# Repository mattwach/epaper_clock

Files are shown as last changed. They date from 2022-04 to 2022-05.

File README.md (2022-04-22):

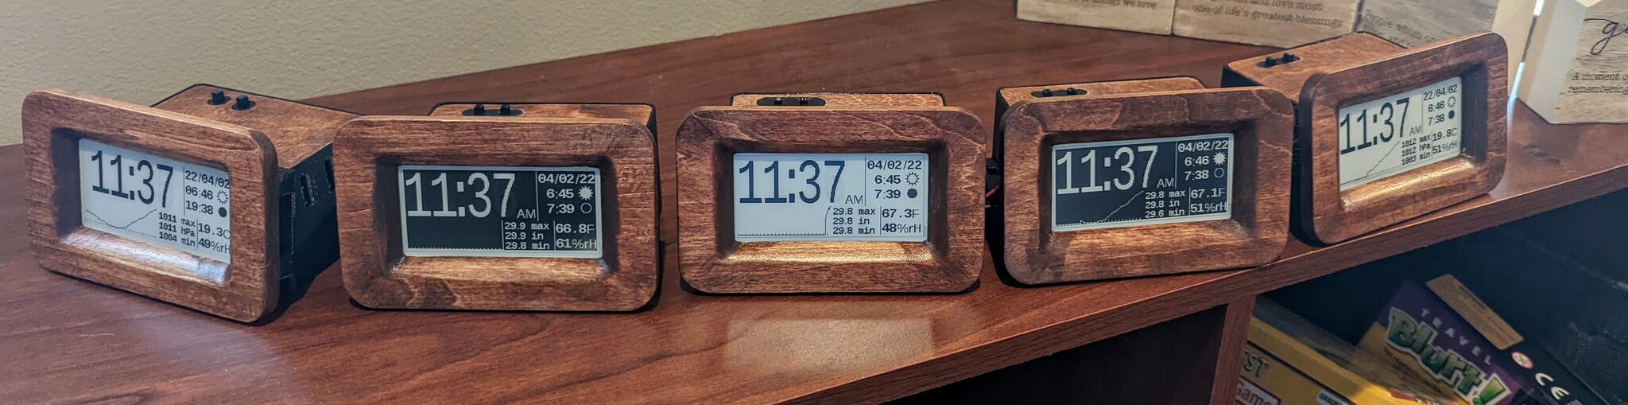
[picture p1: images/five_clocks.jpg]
Five Clocks

# EPaper Clock and Weather Station

This project is an EPaper clock and weather station that automatically sets
itself (via GPS) and can be built to last about 6 months on 4 AAA batteries.
It purposefully does not need any network connections for the sake of security
and reliability.

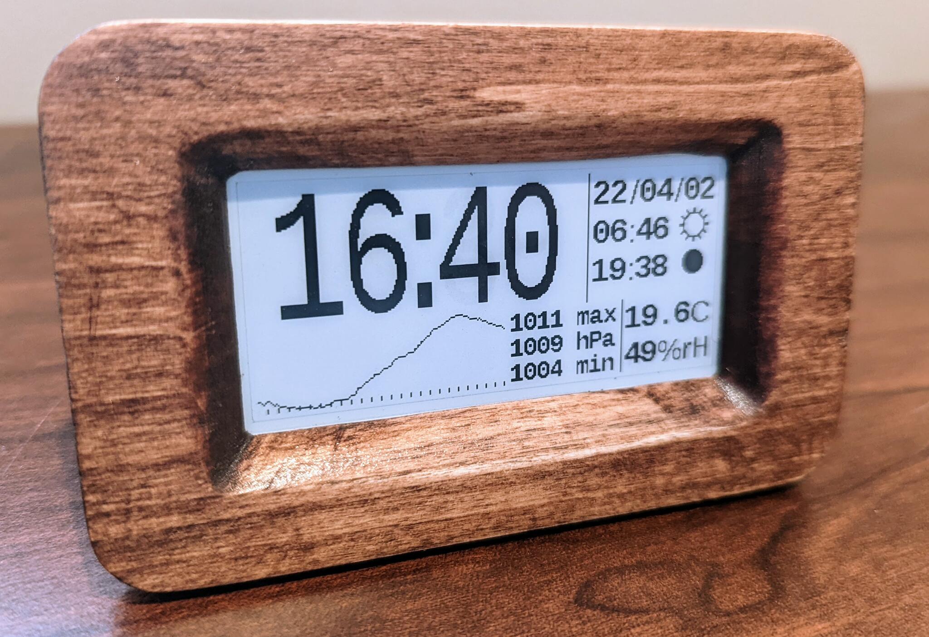
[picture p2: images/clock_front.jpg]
Clock Front


Here is a video overview:

IMAGE ALT TEXT (http://www.youtube.com/watch?v=99J65S5GTPI "EPaper Clock Video")

Features include:

   * Autoset (via GPS)
   * Current temperature.
   * Current humidity.
   * A pressure graph showing pressure over the last 25 hours.
   * Sunrise and Sunset times
   * Current moon phase
   * Select between 12h or 24h modes.
   * Select between English and metric units.

I put together two main variants of the project: "easy" and "low power".

The "easy" version is based on the Arduino Nano.  The intent with this
variation is to minimize cost and part count. The downside is that you'll need
to power the clock from a USB 5V adapter.

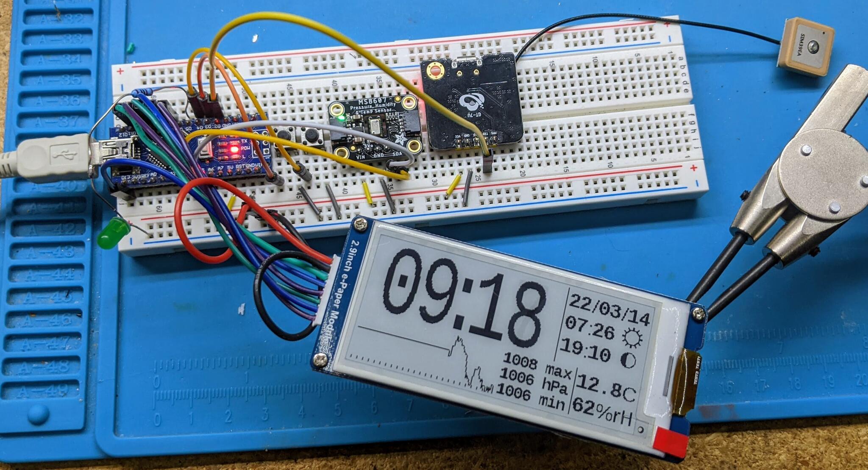
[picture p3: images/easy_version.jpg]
Easy Version


The "low power" version replaces the nano with a bare Atmega328P chip,
configured with a 32k crystal.  Under this configuration, the chip uses < 1
uA except when it is woken up by the crystal once per second.  This means
that the clock can be powered for a long time on batteries, even when power
draw from other devices is accounted for (all devices included draw 30-70
uA during while sleeping, and they are sleeping most of the time).

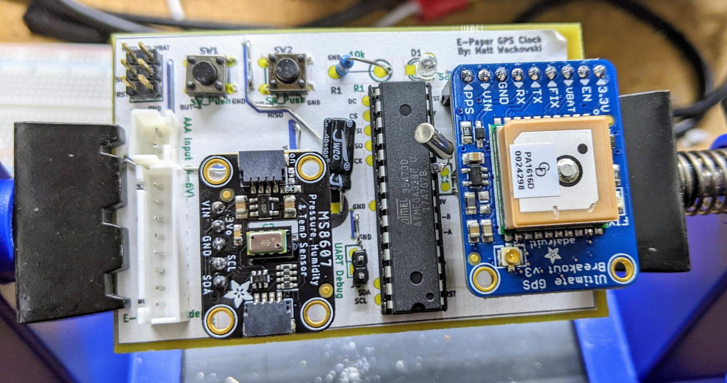
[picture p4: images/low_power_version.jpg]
Low Power Version


Both versions are designed to be buildable on a breadboard for experimentation.
The final board is designed to be buildable by any of several techniques:
prototype boards, CNC milling, chemical etchings, or ordering a PCB from the
provided design files are all options.

# Parts List

## "Easy" version

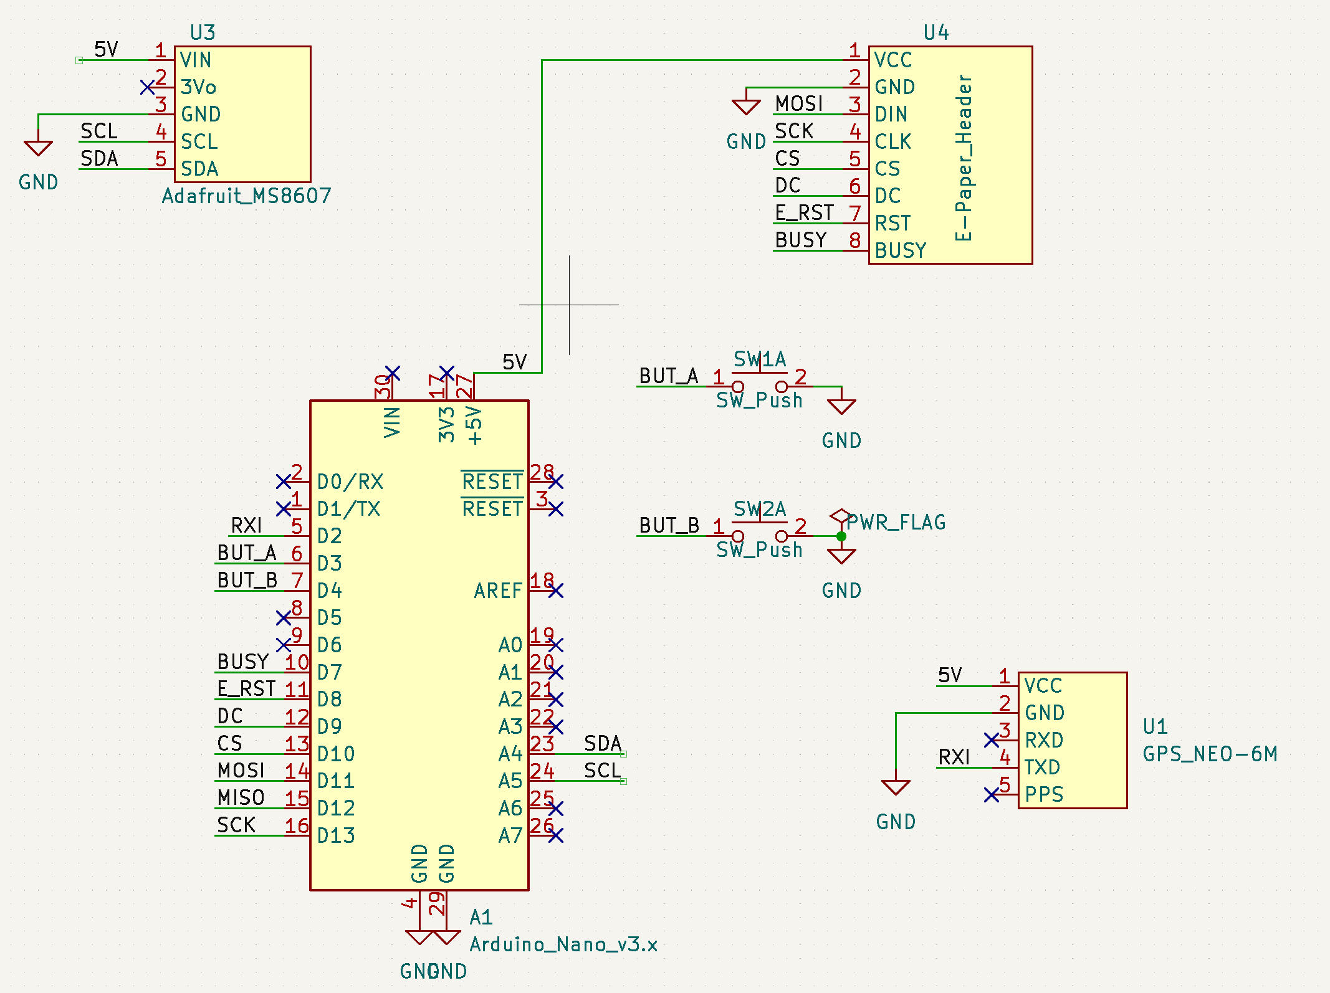
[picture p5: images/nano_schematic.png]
Nano Schematic


   * _Arduino Nano (or clone) ($3)_.  I went with a
     [clone board on Amazon](https://www.amazon.com/ELEGOO-Arduino-ATmega328P-Without-Compatible/dp/B0713XK923) but
     with April 2022 prices, I'd consider ebay as well.
   * _Waveshare 2.9 in EPaper Module ($22)_.  Purchase direct from Waveshare or
     [from amazon](https://www.amazon.com/2-9inch-Display-Module-Two-Color-Interface/dp/B07VD1V1YB).
   * _Adafruit MS8607 Pressure / Humidity / Temperature Sensor ($15)_.
     [link](https://www.adafruit.com/product/4716) I chose this one because of
     it's low power draw.
   * _Any basic GPS module with 9600 Baud TX_ ($12).  I went with
     [this one](https://smile.amazon.com/gp/product/B07P8YMVNT)
   * _Circuit Board_: This might be a
     [prototype board](https://www.amazon.com/ELEGOO-Prototype-Soldering-Compatible-Arduino/dp/B072Z7Y19F) OR
     [a piece of copper clad for CNC](https://www.amazon.com/MCIGICM-Copper-Laminate-Circuit-Single/dp/B01MCVLDDZ) OR
     you might opt to order a [prefabricated PCB](https://oshpark.com/).
   * _A couple of push switches_: [link](https://www.adafruit.com/product/1119)
     These are used to change the UTC time offset and display preferences.
   * _Materials to build a case_: I provide `.3mf`, `.scad`, and `.dxf` files
     if you would like to use a 3D printer, laser cutter, or CNC machine (I
     used a 3D printer and CNC), but you can also do a personalized case if you want.
   * _USB charger and cable_: To power the unit

## "Low Power" version

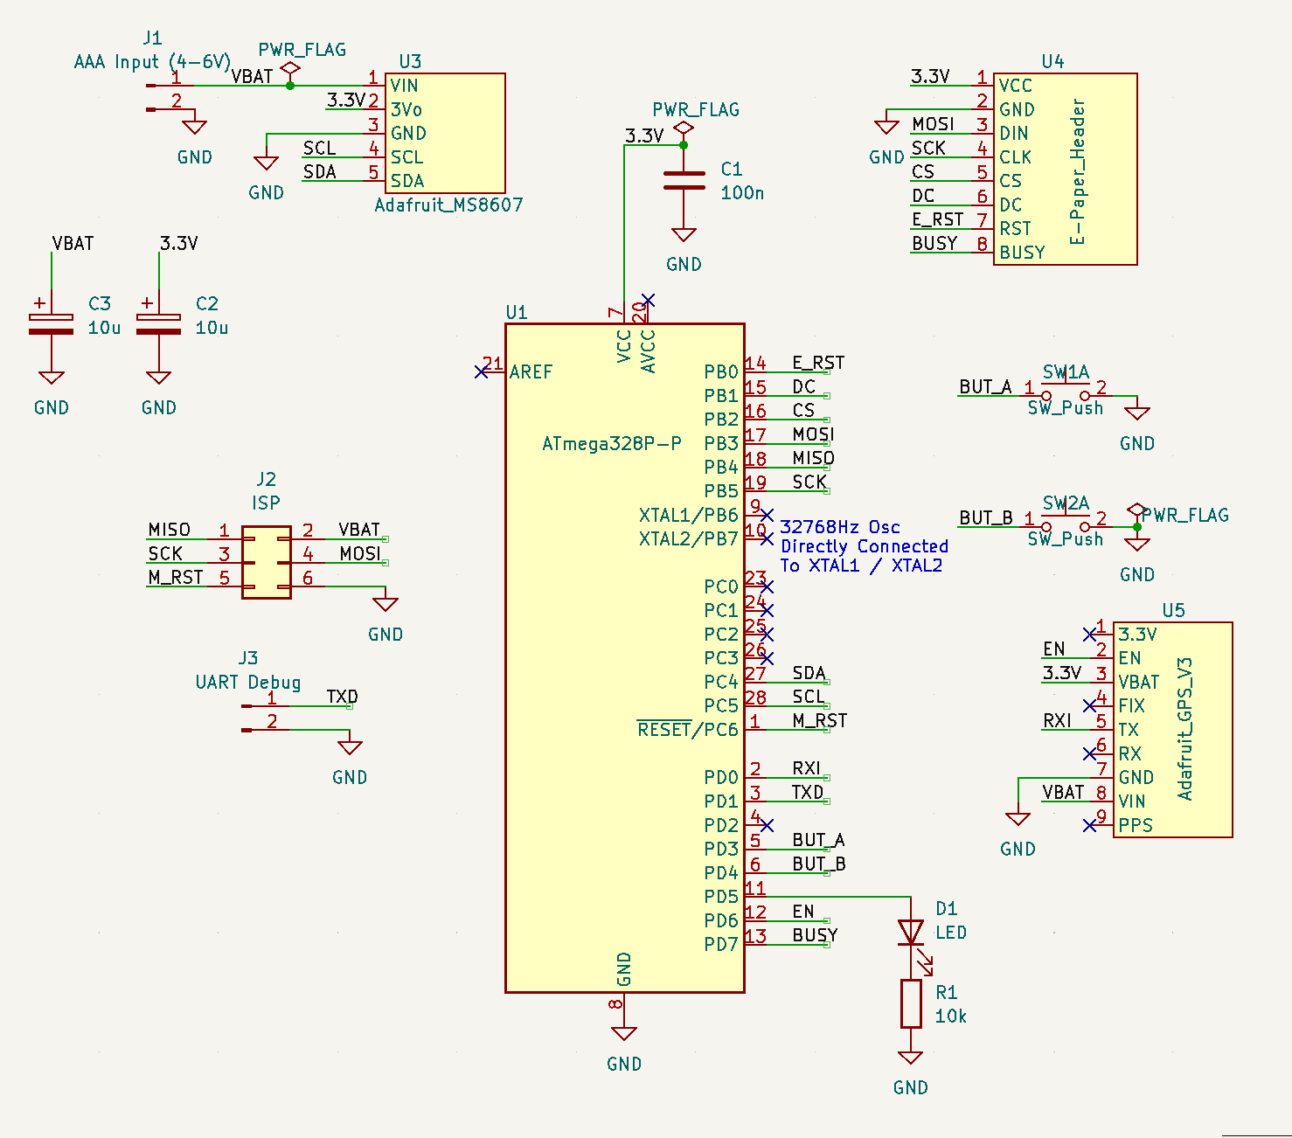
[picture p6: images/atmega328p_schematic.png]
Nano Schematic


From the "easy" version above, you will need:

   * Waveshare 2.9 in EPaper Module
   * Adafruit MS8607 PHT monitor
   * Circuit board
   * Push switches
   * Case materials

You will also need

   * _Atmega328P DIP version ($2)_.
     [link](https://www.digikey.com/en/products/detail/microchip-technology/ATMEGA328P-PU/1914589)
     You can alternately opt for an SMD package version but soldering on the
     32k crystal will be harder.
   * _32768 Hz Crystal (<$1)_. [link](https://www.amazon.com/gp/product/B07Z2V95MJ)
     This oscillator is the key to low power in the design.
   * _Adafruit GPS Module ($30)_ [link](https://www.adafruit.com/product/746)
     This module is a bit higher quality than the one in the "easy" version in
     that it can track more satellites (for faster lock), provides and enable
     pin (for low power) and a port for keeping its memory active (for fast
     relock).  If all those features don't justify the added cost for you, you
     can hack a cheaper module to do the job by adding your own enable FET.  I
     explain how in upcoming steps.
   * _LED + Resistor_  The bare Atmega328P has no way to tell you if it's
     working, locked up, etc.  The blinking light thus provides a 1ms / second
     "heartbeat" that consumes almost no power but provides useful feedback.
     If you don't feel like you need it, you can omit it.
   * A couple of 10 uF and a 100 nF capacitors to smooth the power, which
     ranges from 50 uA to around 5-6 mA when refreshing the screen.
     If you feel lucky, you can try omitting these.
   * A 3x2 pin header for programming the chip via ICSP.  If you only program
     the chip off-board, you will not need this.
   * _Optional: A 1x2 pin header for UART debugging_.  You will only need this
     if the board is acting erratically.

## Arduino Mini version

I said there were two version but this is a bonus one (V2.5?).  It exists
because we live in a "parts drought" where chips like the Atmega328P go out of
stock for long periods.

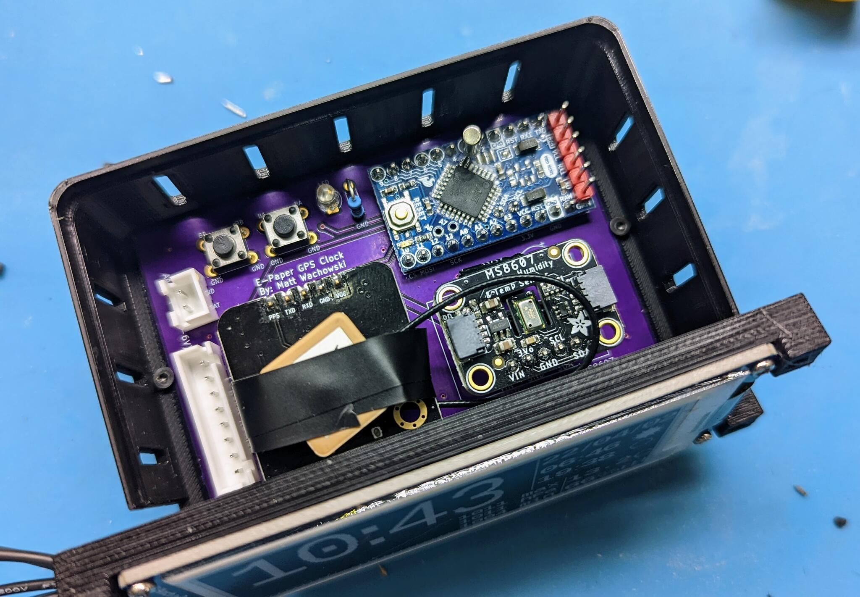
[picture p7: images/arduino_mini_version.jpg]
Arduino Mini Version


You can run this version with the "easy" firmware or, if you have
the soldering confidence, you can solder a 32k crystal on the board and go with the
32k version of the firmware (more details on the next section).

Here is the schematic.  This one is wired with a "cheap GPS" solution but you
can also go with the Adafruit GPS if you replace the GPS part of the schematic
with the Adafruit setup (as illustrated in the low power schematic).

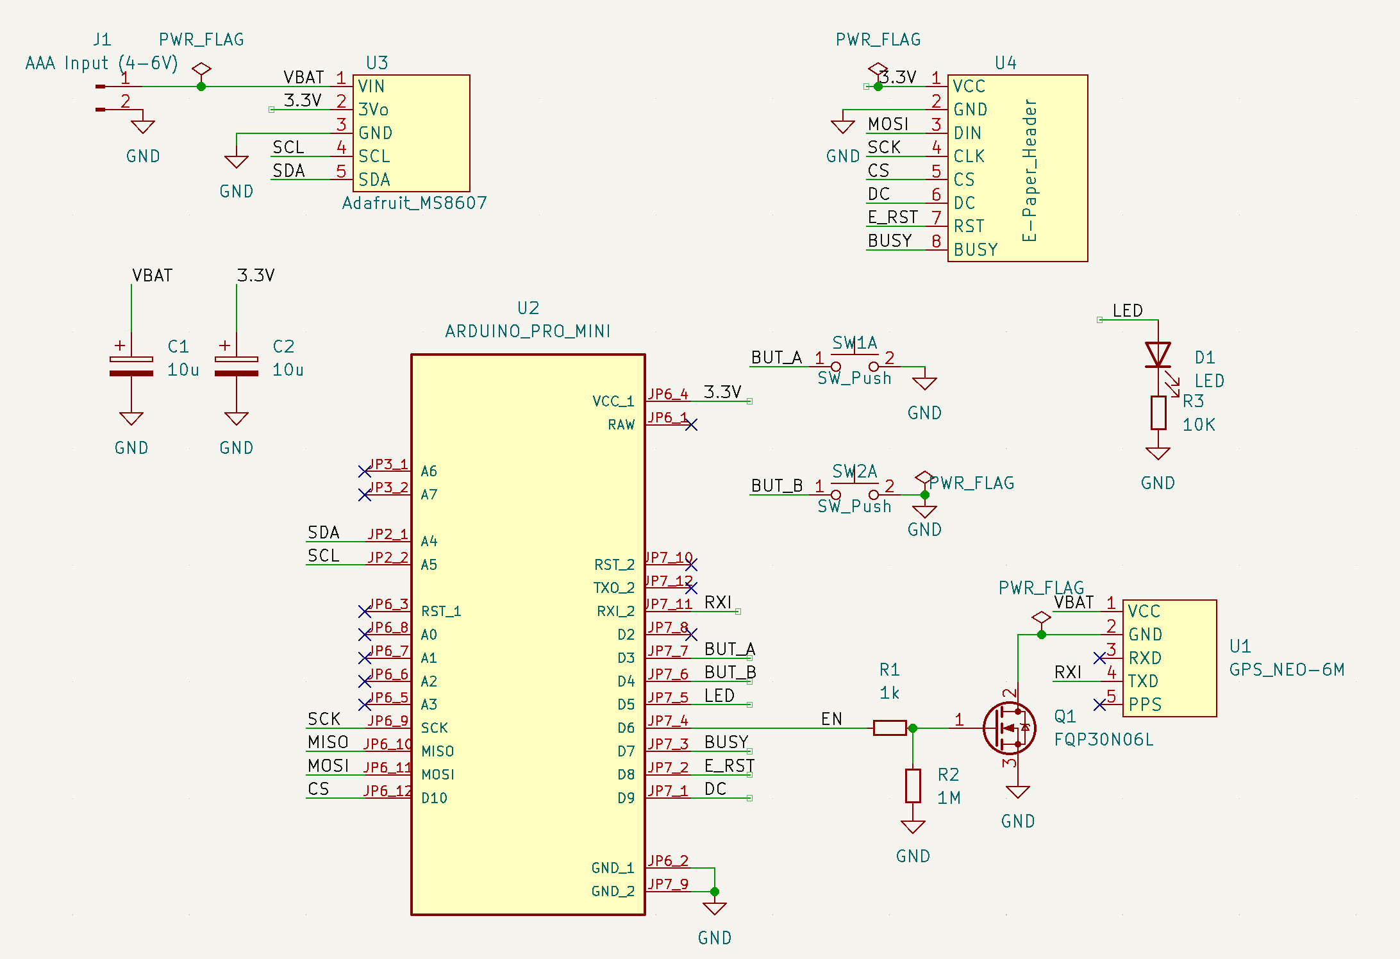
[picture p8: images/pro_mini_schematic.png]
Pro Mini Schematic


## Cheap GPS

That Adafruit GPS unit is expensive compared to the competition.  If you don't
think the added features (described above) are "worth it" you can drop in any
GPS module that transmits NMEA strings at 9600 baud (which is most of them).
**But now there is a new problem to solve:** most of these units lack an
enable/disable pin and GPS units typically consume 30-60 mA of power.  You can
hack a disable switch in using a N-MOSFET (or similar).  Here is the basic
idea:

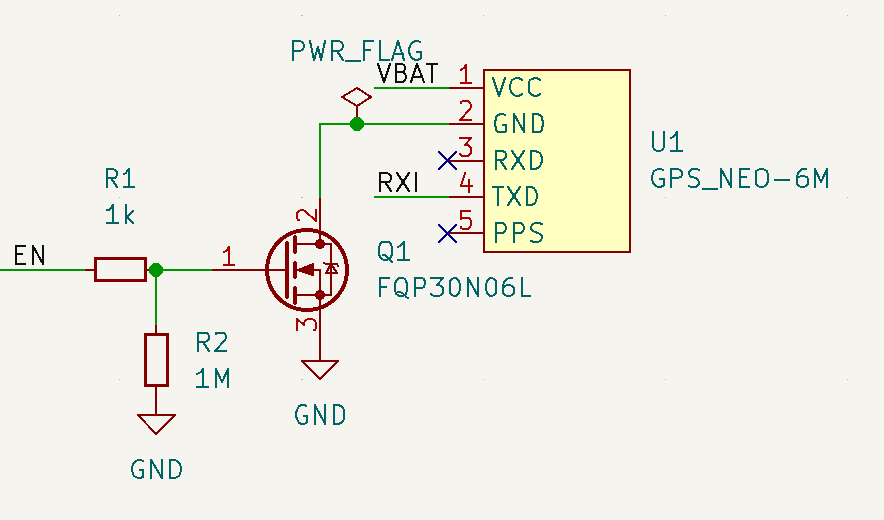
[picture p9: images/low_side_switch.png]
Low Side Switch

[try it out](http://www.falstad.com/circuit/circuitjs.html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)

This power circuit has trade-offs.  See Appendix B for details if you are
interested in learning more about them.

## Low Power Hardware Mods

If running the "easy" version, you don't need to read this section.  For the
low power version, these mods will improve battery life significantly.

For illustration we will assume power is coming from a set of AAA batteries
which can supply 1000 mAh.  Let's assume you are using the 32k Adafruit version
and are doing no mods.  Here is an example power breakdown:

   * "Sleeping/Off" CPU, GPS, MS8607, and EPaper: Measured at 30-70 uA (we'll
     say 50uA)
   * Screen Update: 5 mA for 2 seconds once per minute: 5 * 2 / 60 = 166 uA
   * GPS Update: 50 mA for 10 seconds once per day: 50 * 10 / 86400 = 6 uA
   * MS8607 LED: 100 uA
   * Adafruit GPS pullup resistor: 500 uA

Thus we have 822 uA of average current draw which amounts to ~50 days of power.

Remove the MS8607 LED and the GPS pullup and we reduce power usage to 222 uA
which is ~187 days of power, significantly more!

### Remove the LED from the MS8607

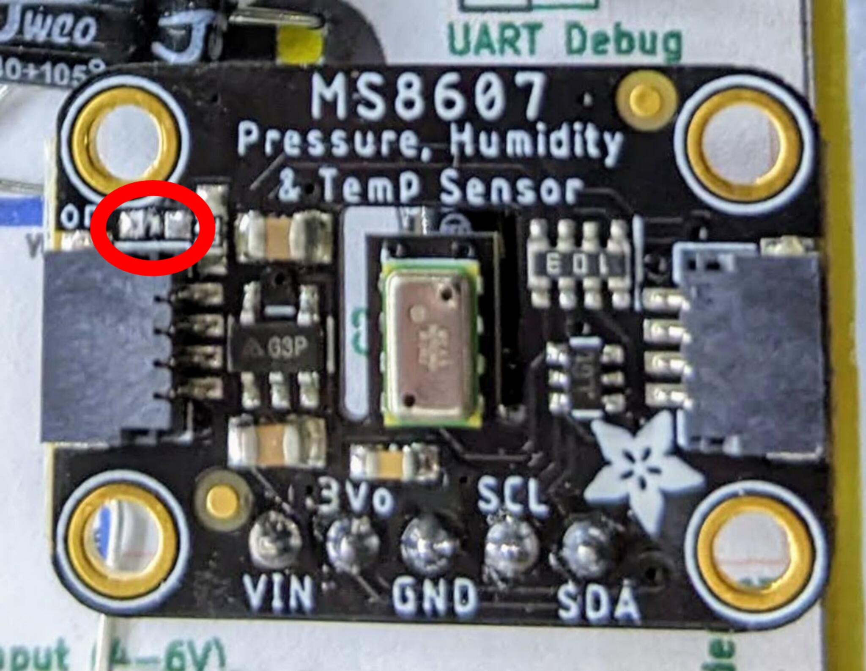
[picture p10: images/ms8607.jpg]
MS8607 Mod


### Remove the "pullup" enable resistor from the Adafruit GPS module (if using)

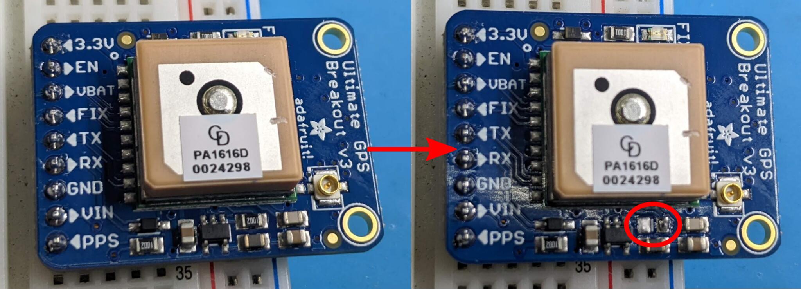
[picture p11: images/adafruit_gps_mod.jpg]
Adafruit GPS Mod


This was added by Adafruit to make the EN pin ignorable by inexperienced users.
But it has a big downside: when you pull it to ground (to disable the GPS) -
about 500uA is lost to heat in that pullup resistor!  Since the enable pin is
actively driven in the 32k oscillator design, you can remove the resistor.

### Pro mini mods

Google search "[Arduino mini low power](http://www.google.com?q=arduino%20mini%20low%20power)".
The TLDR is that you'll want to remove the voltage regulator and LED to reduce
power usage.  We are using the MS8607's voltage regulator (3.3V, 35-55 uA power
lost at idle) to power the pro mini.

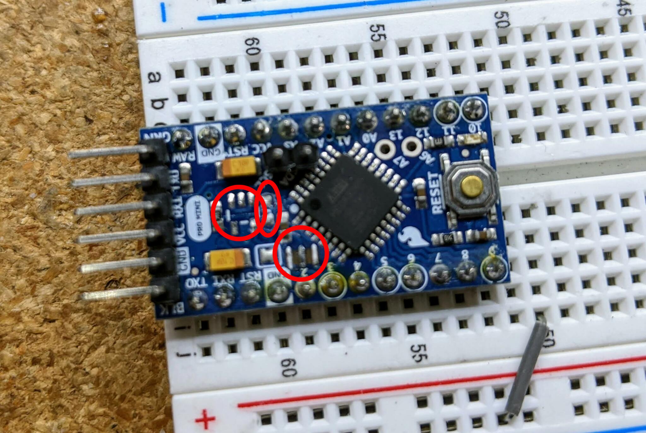
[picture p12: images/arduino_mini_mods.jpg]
Arduino Mini Mods


In the photo above, I also removed the crystal oscillator (lower right) to prep
the chip for a 32K crystal.  This is *only* for the 32k crystal version and
*only after* the fuses have been changed on the pro mini as explained later.

## Other notes

The "easy" design actually contains the same firmware features from the 32k
design you can take advantage of if you want:

   1. D5 is still driven as a status light so you can connect an LED/Resistor
      here if you want to.
   2. D6 is still driven as a GPS enable/disable so you can use it to turn the
      GPS on/off if you want to.

# Firmware Upload

This firmware is open source and is located at [link here].

I have included prebuilt firmware `.hex` files in the `firmware/` directory so
you likely do not need to build the code.

Still want to build it and possibly add your own modifications?  Here are some
tips:

## OPTIONAL: Building the .hex firmware files yourself

Note that this code does not use Arduino libraries because the resulting code
would be too big to fit on the Atmega328P (and it's my personal preference).
Instead it's written in C using the same AVR base libraries that Arduino also
uses as a base.  If you want to compile the code, you will need to install the
(free) `avr-gcc` tools, then go to the `firmware/` directory and type

    make

If the code builds, you'll want to open the `Makefile` and look at
these options:

    # This is the Low-power stand alone chip configuration.
    CLOCK_MODE ?= USE_32K_CRYSTAL
    UART_MODE ?= HARDWARE_UART
    F_CPU ?= 8000000
    
    # This is the easy-to-build firmware that is based on an Ardino Nano
    #CLOCK_MODE ?= USE_CPU_CRYSTAL
    #UART_MODE ?= SOFTWARE_UART
    #F_CPU ?= 16000000

If you are building the 32k crystal firmware, you are done.  If building the
nano version, you'll need to comment out the 32k lines and uncomment the nano
lines, then `make` the firmware again.

There is also a special debug mode that dumps log messages over the hardware
UART at 9,600 baud.  I think you can ignore it for now but keep it in mind as
something that might be useful for troubleshooting later:

    # Uncomment to activate debug via the UART TX (9600 baud)
    #DEBUG_CFLAG := -DDEBUG

Finally, you can decide how often the GPS should be activated by changing a
couple of variables.  By default, currently runs once per day but will run less
often if GPS takes a long time to lock in order to reduce battery drain.  Read
all about it in `src/gps.c`

## ICSP hardware

This section is for those uploading code to a stand-alone Atmega328P chip (or
burning Arduino Pro mini fuses).

You'll need what is called an ISP (or ICSP) programmer.  You can buy these for
around $10 [on amazon](https://www.amazon.com/gp/product/B0885RKVMC) or make
one yourself with a spare
[Aruino Uno/Nano](https://create.arduino.cc/projecthub/arjun/programming-attiny85-with-arduino-uno-afb829)
The options continue but I'll leave that to a Google search for
"[Arduino ISP Programmer](http://www.google.com?q=Arduino%20ISP%20Programmer)".
I will note that a lot of these guides assume your real goal is to install a
bootloader but for our case, no bootloader is needed as you'll be uploading
the `.hex` file directly.

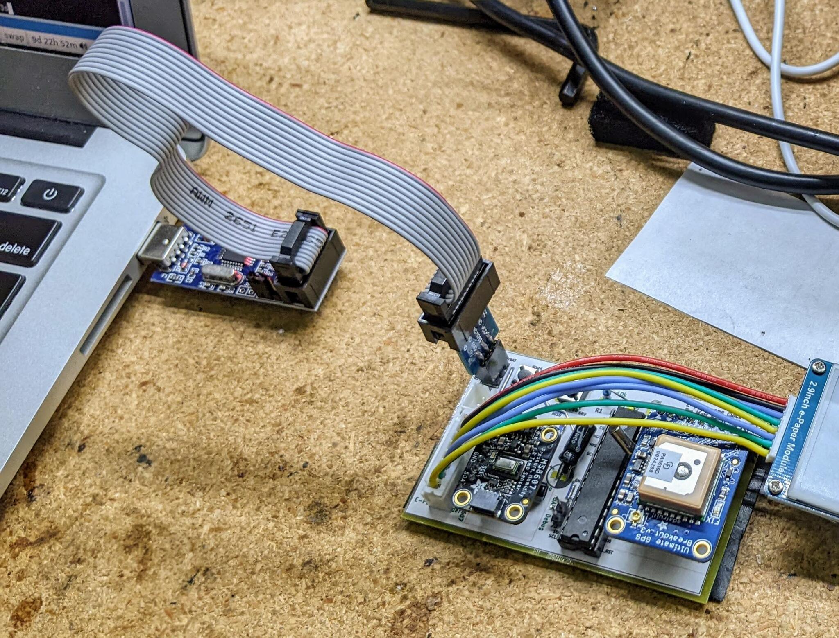
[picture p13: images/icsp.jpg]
ICSP Hardware


### Brownout detection

On my particular Atmega328P, the brownout detection as set to 3.5V (old version
of the chip?  A clone?) so I disabled
brownout detection with this command:

    /usr/bin/avrdude -patmega328p -cusbasp -Uefuse:w:0xFF:m

Your options may be different depending on your ISP programmer (the -c option).
You probably won't need it but just in case...

## Using avrdude

The popular Arduino IDE uses a free utility named `avrdude` to upload the hex files it creates to your
Uno/Nano/etc.  You can also download and use `avrdude` directly from the commandline
instead.  To get the correct options for the tool you can:

   1. Run an upload (blinking light demo or something) with the Arduino IDE
      with output logging turned on.  Then copy the command it used.  OR
   2. Read the official [avrdude docs](https://www.nongnu.org/avrdude/) OR
   3. Read one of the many many [avrdude tutorials](http://www.google.com?q=avrdude%20tutorial) on the internet.

For your reference, here is the `avrdude` command I used for the nano version (via `make upload`):

    /usr/bin/avrdude \
			-v \
			-patmega328p \
			-carduino \
			-P/dev/ttyUSB0 \
			-b57600 \
			-D \
			-Uflash:w:epaper_firmware_using_arduino_nano.hex:i 

and this is what I used for the ISP version:

    /usr/bin/avrdude \
			-v \
			-patmega328p \
			-cusbasp \
			-Uflash:w:epaper_firmware_using_arduino_nano.hex:i 

but there is a fair chance your setup is a bit different than mine.

## 32K Crystal

If you are building the "easy" version, skip this section.

If you are using the 32k crystal firmware, the crystal will need to be
installed for the firmware to operate.

**First (!)** You'll also want your ATMega328P set to use the internal 8 Mhz
crystal.  It's important to do this step first because the 32k crystal is using
the pins of the old crystal.  If you don't change these fuses, the chip will
become non responsive until you reconnect a 8 or 16 Mhz oscillator which
would be an annoying pain.  As far as I know the Arduino pro mini also needs
ISP to change the fuses (but I could be wrong).  I looked up "Arduino ISP" to
get the correct pin mappings for interfacing an ISP connector with a breadboard
as shown:

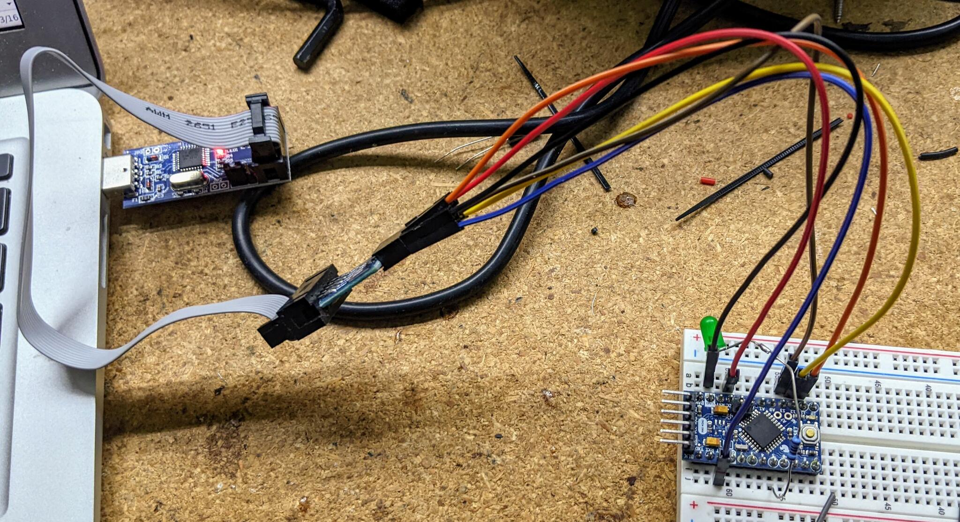
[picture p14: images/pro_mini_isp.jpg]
Pro mini ISP


With my ISP programmer, I check with this command:

    $ avrdude -patmega328p -cusbasp
    ...
    avrdude: safemode: Fuses OK (E:FF, H:DE, L:E2)

The `L:E2` _is the setting you want for internal 8mhz_.  If your value is
different, you can update it with a command similar to this one:

    /usr/bin/avrdude -patmega328p -cusbasp -Ulfuse:w:0xE2:m

Then recheck.

Onto the hardware mod.  Here is a 32k crystal installed on a Atmega328P 

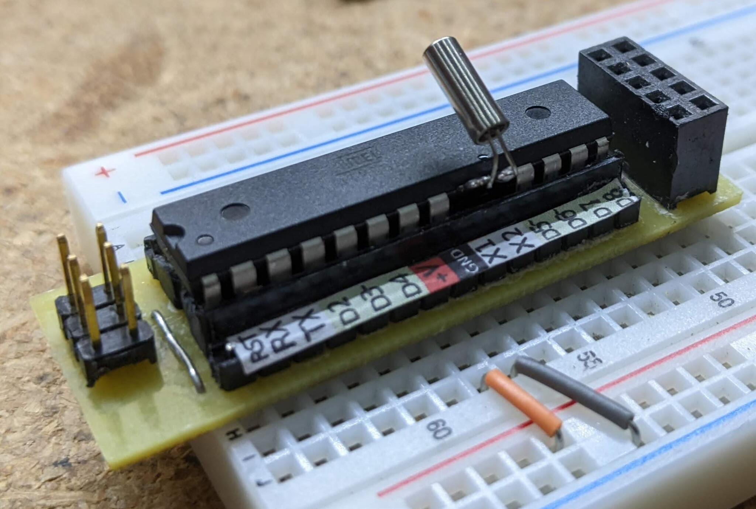
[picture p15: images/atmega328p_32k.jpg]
ATMega328P 32k Crystal


And on a Arduino Pro Mini (which also has the low power mods as-explained
earlier)

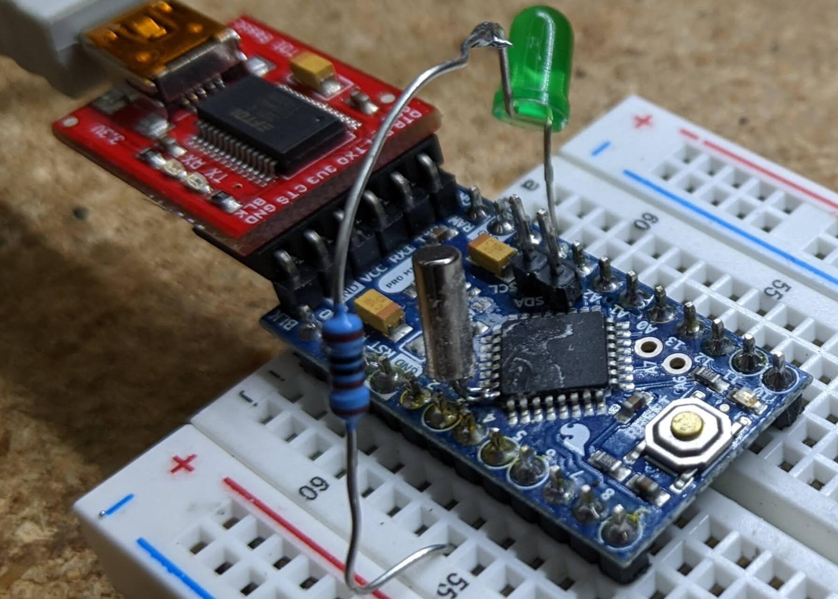
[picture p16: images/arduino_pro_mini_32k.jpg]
Arduino Pro Mini 32k Crystal


Attaching directly to the pins is recommended to reduce stray capacitance.  Too
much capacitance and the crystal will take longer to start oscillating (or fail
to start).

## Optional: First Steps

Easy Version

   * You can verify that things are OK so far on a breadboard by connecting
     just a LED/Resistor to D5 and uploading the firmware.  If all is well, the
     light will briefly flash once per second.
   * Next, you can add the EPaper display.  None of the data will be correct on
     the display but is should show something.
   * Next, add the PHT module
   * and finally the GPS module.

At this point, we are "done and can transfer everything over to a more permanent
fixture"

# Circuit Board assembly

Here you have the option of using a perf board, cutting the board with a CNC or
sending the design to a fab for manufacture.

The design files can be found in the `schematics/` directory and loaded into
Kicad.  There are three hardware flavors to choose from (all shown from behind
since that is how you would wire them by hand):

"Easy" Arduino Nano + Cheap GPS (always on)

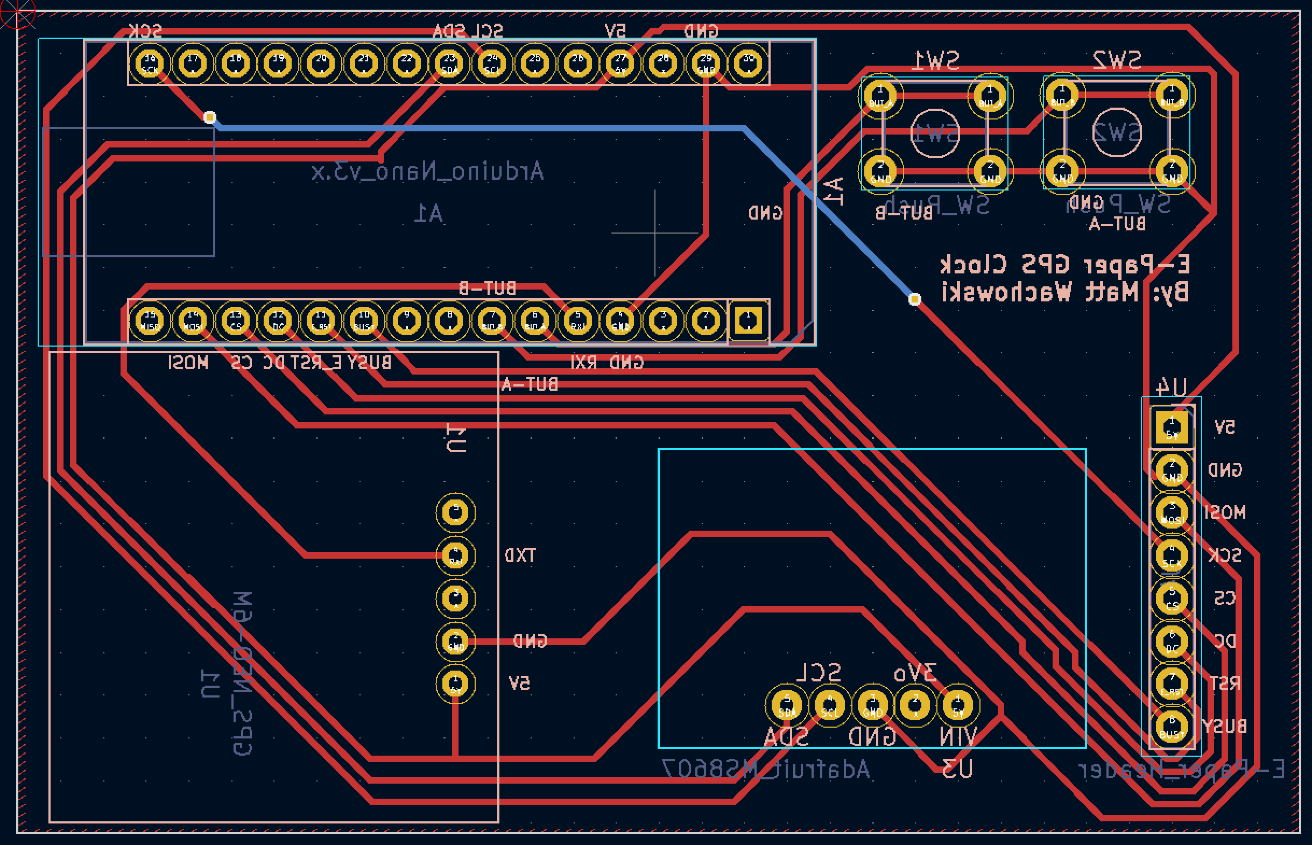
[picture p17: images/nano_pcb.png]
Arduino Nano PCB


Raw ATMega328P + Adafruit GPS (low power)

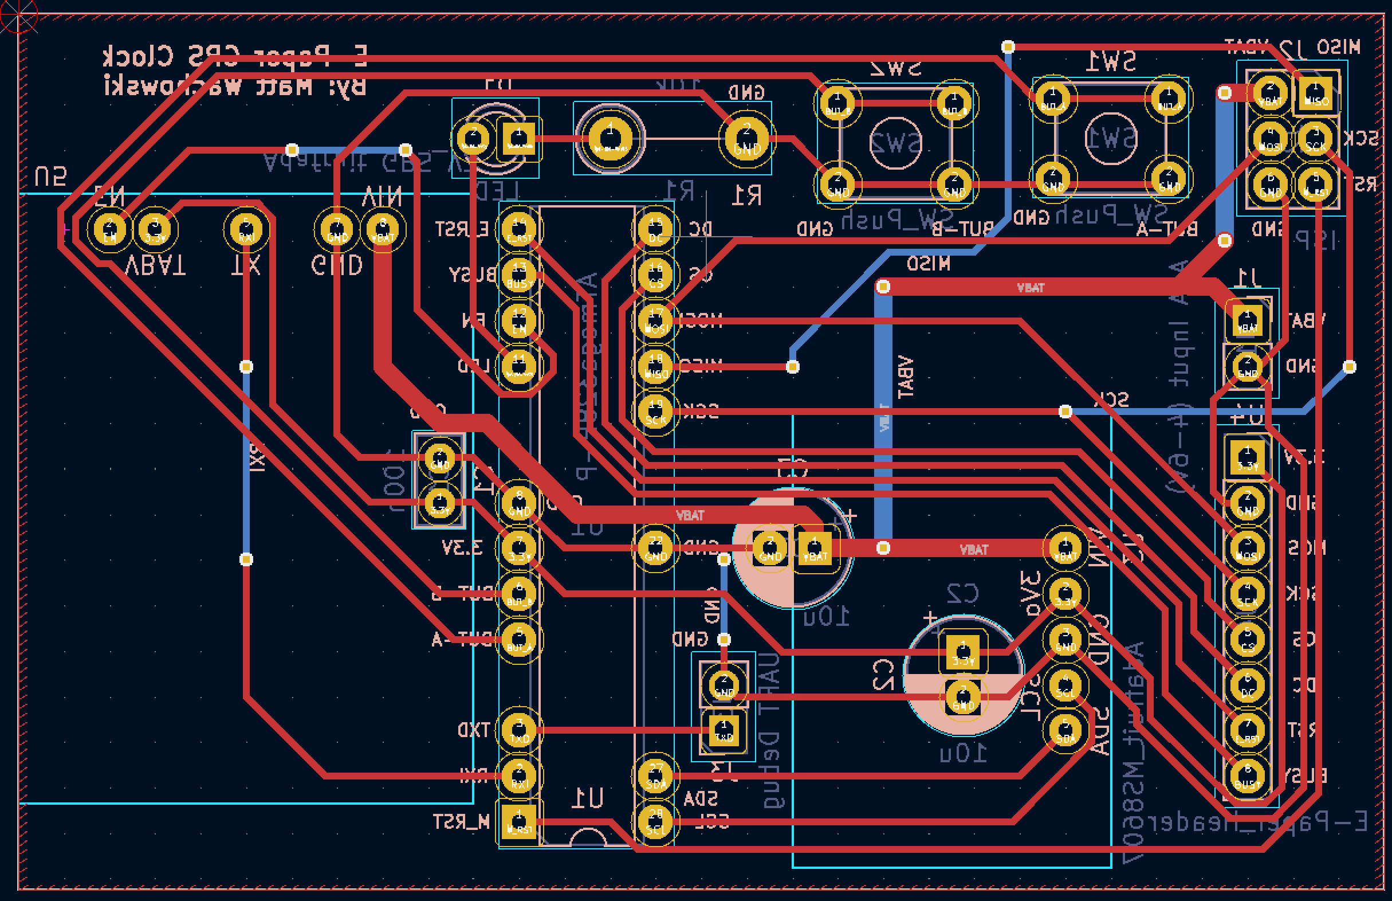
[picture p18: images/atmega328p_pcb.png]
ATMega328P PCB


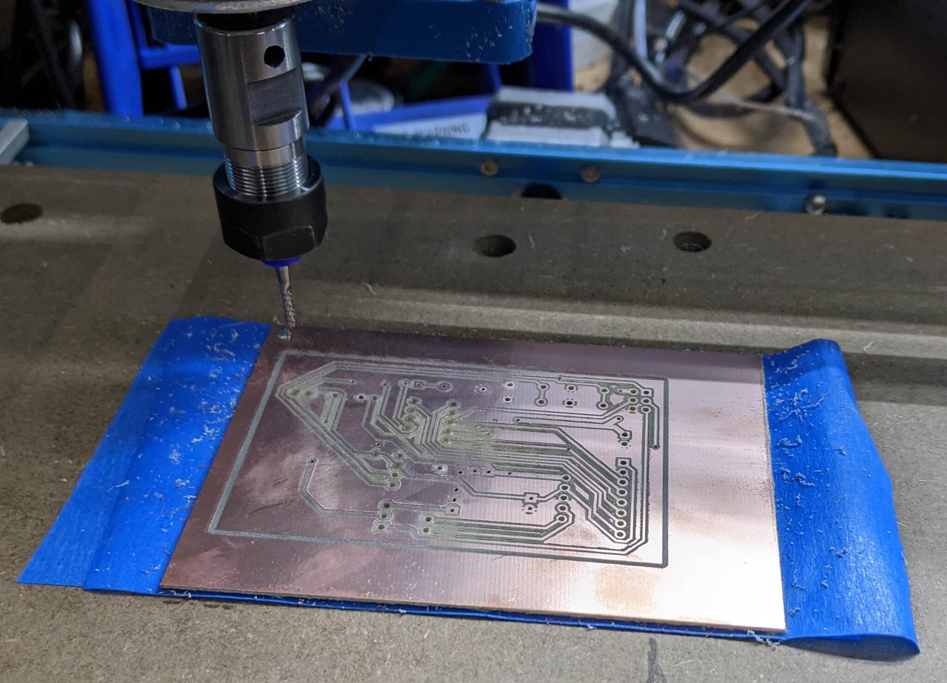
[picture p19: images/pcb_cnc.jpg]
PCB CNC


Pro Mini + Cheap GPS with MOSFET power cutoff

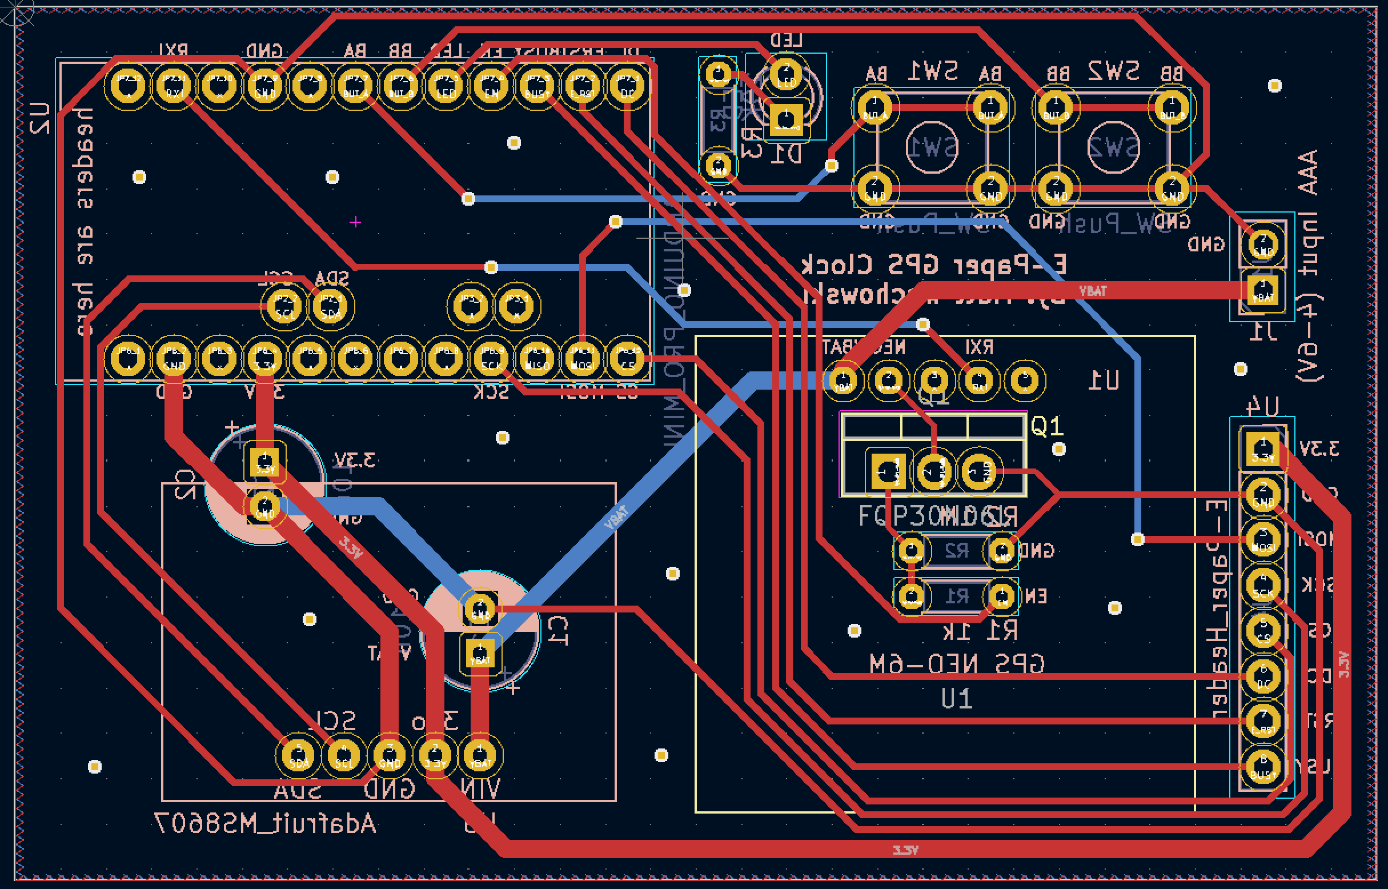
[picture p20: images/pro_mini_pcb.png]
Pro mini PCB


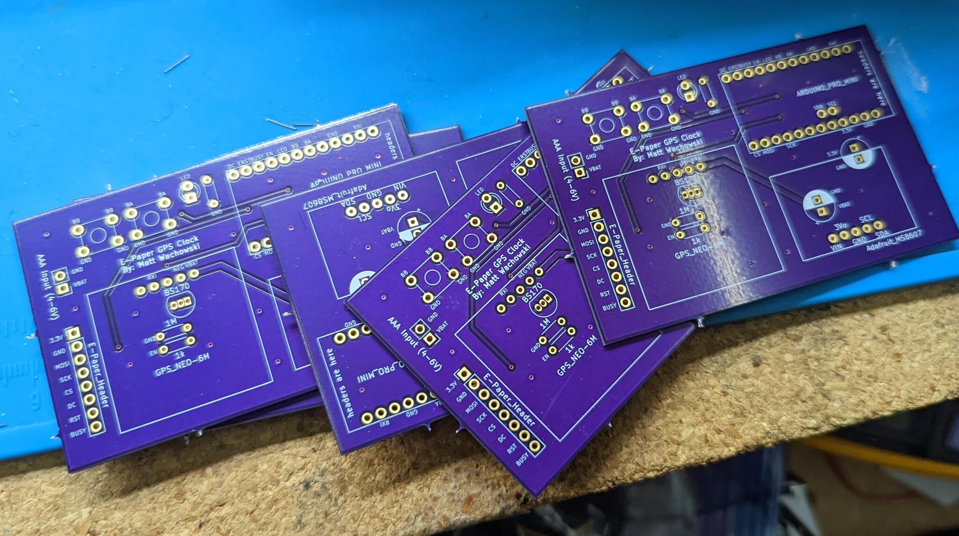
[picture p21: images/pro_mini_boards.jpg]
Pro mini boards


As can bee seen above, I cut the ATMega328P version with my CNC machine.  If
you have not used CNC to cut a PCB and are interested, try a google search for
"[3018 PCB](http://www.google.com?q=3018%20PCB)" and you'll
find many videos and articles on the topic.  I may do my own tutorial in a
separate article in the future but, since CNC is optional here it's not a good
place to go into details.  Isolation clearances are 0.4mm but you can go
narrower (probably not wider).  I used Flatcam to convert Kicad's Gerber output
to G-Code.  I included my Flatcam project in the schematic directory.  I also
included the G-Code files I sent to my 3018 CNC machine.  If you have a 3018
CNC, you can probably directly use the G-Code files, but do a "dry" run without
a bit first to make sure things look sane.

Anyway, when the circuit is finished and put together, it should function like
it did on the breadboard.  If you hold the select button on startup,
the GPS will be powered down (if possible) and you can try measuring the
current draw with your multimeter.  If you see 50-110 uA, we are seeing the
same result.  If not, you can unplug devices one at a time to try and narrow
down the parasitic power draw (assuming you didn't solder everything
permanently to the board).

# Case Design

You can design any type of case you want and I encourage you to be creative
here!  But I'll also share how I made my case and provide all of the files in
case you are interested in a more streamlined progression.

All of my design files are in the `case_design/` folder of the project.

My design uses a 3D printed support structure and two CNC parts: a top cover
and front panel.  The CNC parts are made of wood because I thought it would
look nicer than plastic.  I designed the whole thing upfront in OpenSCAD

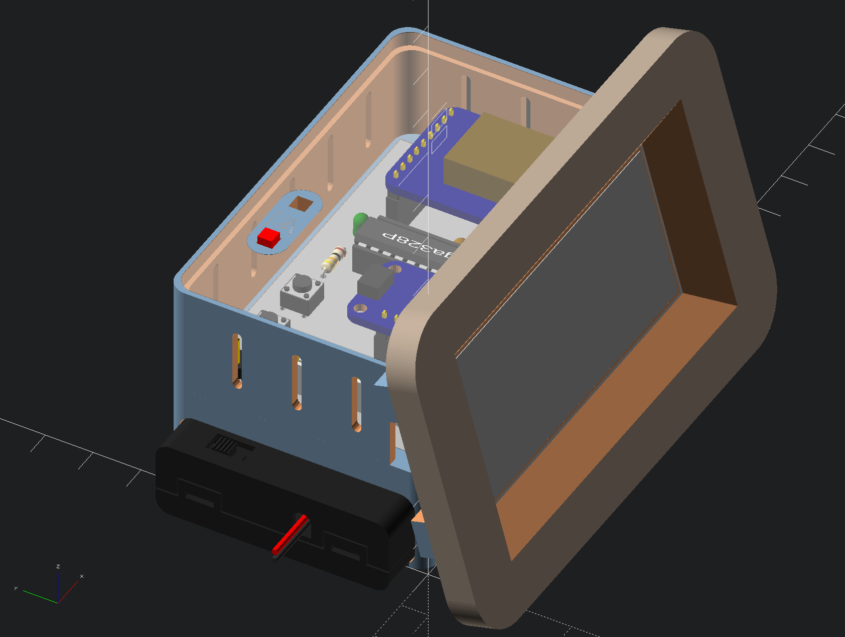
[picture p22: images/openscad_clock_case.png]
OpenSCAD clock case


I printed the main structure with 0.2mm layer height.  On my printer, the print
took a little over 5 hours.

I used OpenSCAD's "projection" feature to created 2D DXF files for the top
cover and front plate.  At this point, I would normally use a free program
called "Carbide Create" to make G-Code for the CNC machine.  But my face plate
has a 45 degree chamfer to the screen and Carbide Create is too basic of a
program to handle this well (at least my Google searches through forums on
    their website led me to that conclusion).  So I tried a different program
called "CamBam" and it worked very well.  CamBam is not free but you can use it
40 times for free.  I'm leaning toward purchasing the program but want to
experiment with it on a few more project first.

Some build photos:

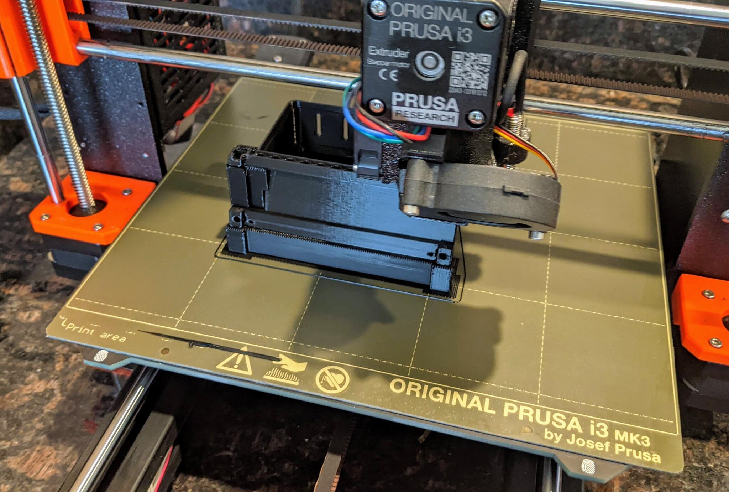
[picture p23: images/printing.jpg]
3D Printing

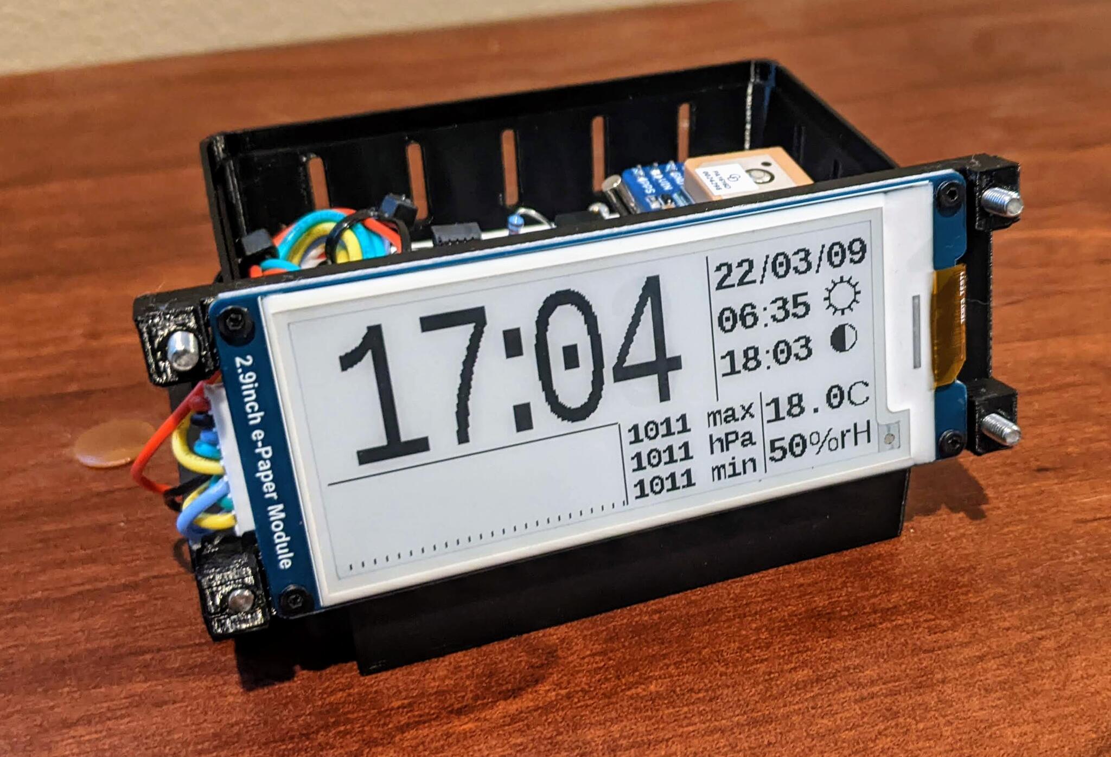
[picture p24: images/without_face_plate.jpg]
Without Face Plate

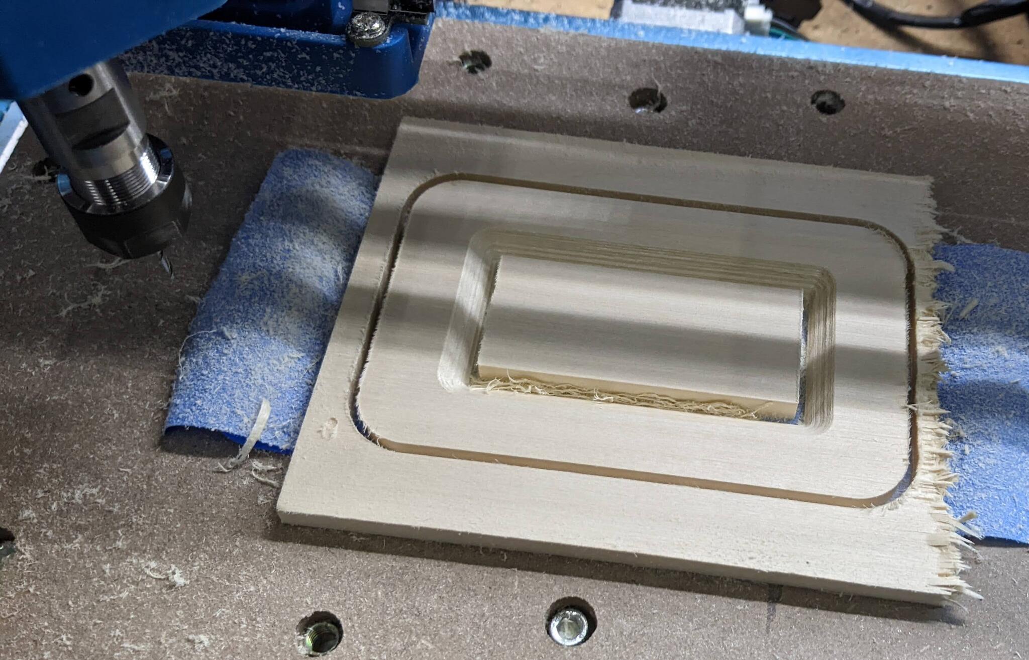
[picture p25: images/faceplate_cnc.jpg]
Face Plate CNC

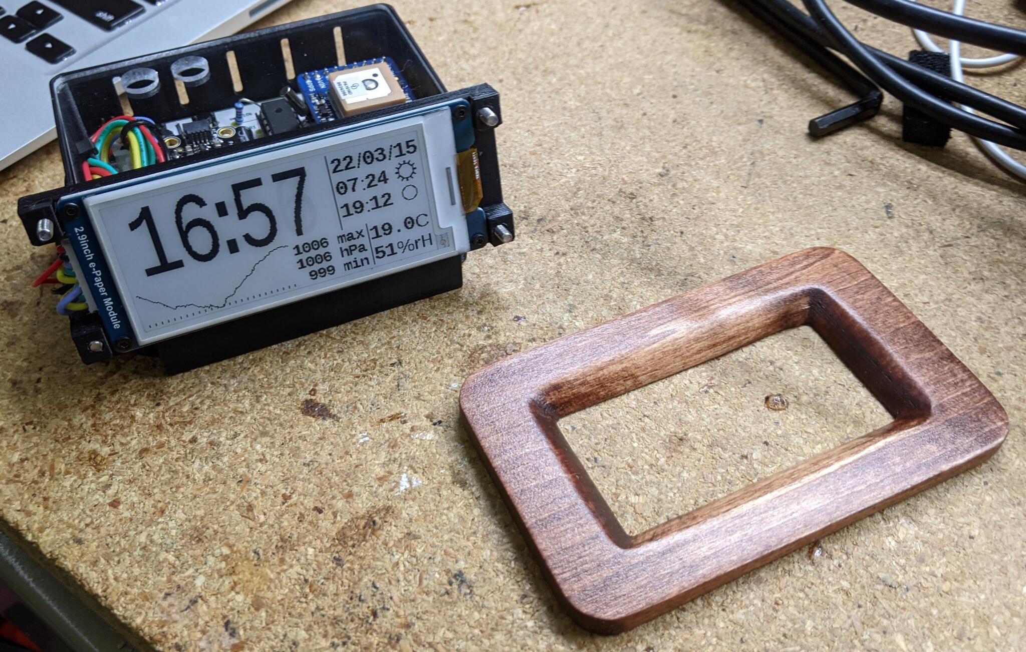
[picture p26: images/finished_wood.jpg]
Finished Wood

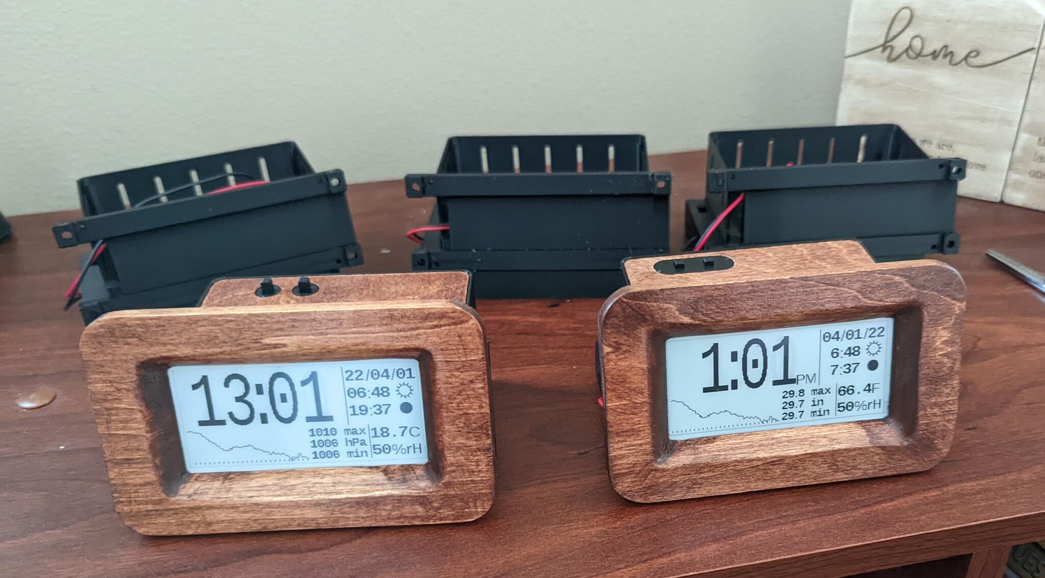
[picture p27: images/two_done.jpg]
Two Done


# Appendix A: Optional Clock Drift Correction

Your 32k/CPU crystal will not be perfect.  When the GPS turns on, it will
correct the drift.  But if the drift is bad or your GPS signal is bad, you can
also apply a correction in the firmware.  This currently requires you to build
the code.

At the top of `main.c` there are some commented out defines:

    // Clock drift correction
    // If your clock runs too fast or too slow, then you can enable these
    //#define CORRECT_CLOCK_DRIFT
    // number of seconds that a second should be added or removed
    //#define CLOCK_DRIFT_SECONDS_PER_CORRECT 1800
    // define this if the clock is too slow, otherwise leave it commented out
    //#define CLOCK_DRIFT_TOO_SLOW

You can uncomment all of the `#define` statements above to enable the correction.
You only uncomment `CLOCK_DRIFT_TOO_SLOW` of your clock is falling behind.
If your clock is too fast, leave it commented.

The only thing left to do is set `CLOCK_DRIFT_SECONDS_PER_CORRECT`...

### The math way

Wait a handful of hours, then see how much the clock has drifted.  For example,
you might wait 23 hours.  If at that point you see the clock has lost 10
seconds, then your correction would be: (3600 * 23) / 10 = 8280 seconds
per correction.

    #define CORRECT_CLOCK_DRIFT
    #define CLOCK_DRIFT_SECONDS_PER_CORRECT 8280
    #define CLOCK_DRIFT_TOO_SLOW

If you already set `CLOCK_DRIFT_SECONDS_PER_CORRECT` and find you want to fine
tune it _even more_, then you need to add (if too slow) or subtract (if too
fast) `int(SECONDS_ON / CLOCK_DRIFT_SECONDS_PER_CORRECT)` to the error term
in the denominator to account for the already-corrected error seconds.
Building on the example above, if _we were still_ 2 seconds slow after 20
hours, the calculation would be.  (3600 * 20) / (int(3600 * 20 / 8280) + 2) =
7200.

### The non math way

Just try a number like 5,000 and refine it as you note that the clock is still
to fast or too slow.  Still too slow?  Try 2,500.  Too fast?  Try 10,000.  Keep
notes and iteratively refine it to some acceptable value just like the number
guessing games you may have played at some point.

# Appendix B: Cheap GPS power control (The tale of the BS170 N-MOSFET)

Revisiting the power control circuit described in the "Cheap GPS" section.

Low Side Switch
[try it out](http://www.falstad.com/circuit/circuitjs.html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)

The power cutoff circuit above is called a "low side switch".  It's benefit is
that it's relatively easy to understand and the part count is low.  That said,
there are some design concerns:

   * The ground of the GPS is not tied to GND but on the MOSFET drain.  This 
     means that the UART signal from the GPS to the microcontroler will have
     the MOSFET voltage drop added to it (Vds), increasing noise sensitivity
     and possibly causing outright errors. 
   * You would not want to use this design if your microcontroller inputs
     are specified as 3.3V maximum (the ATMega328P I chose doesn't have this
     limitation).
   * 3.3V (EN pin above) is not a very strong turn-on voltage for a typical MOSFET.

But hey, the UART is a digital signal and the ground difference isn't *that*
much so maybe it will work anyway?  I tried it and it worked fine... at first
but I came to discover over time that it was not reliable.  To understand
*why*, we refer to the characteristic curves of the BS170 I originally chose as
my N-MOSFET:

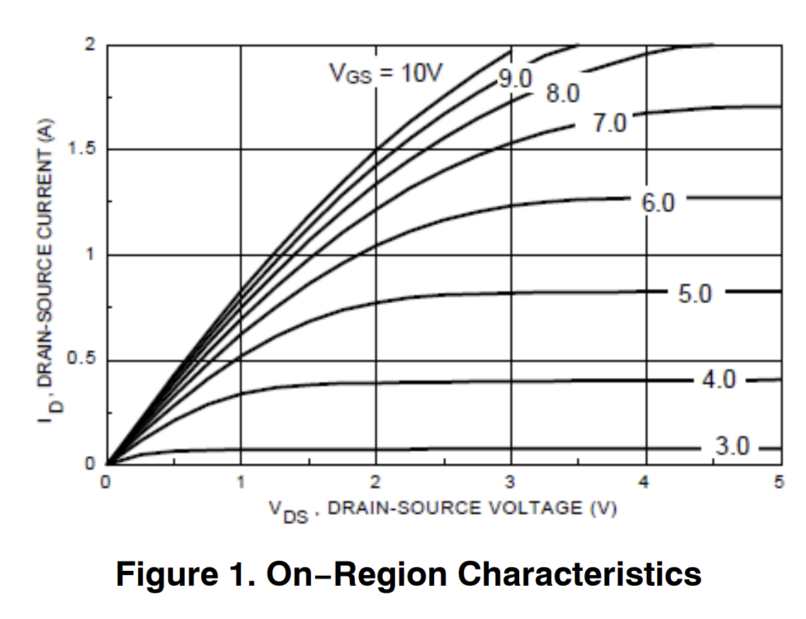
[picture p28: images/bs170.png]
BS170 Curves


At 3.3V on the X axis we will be sitting between the 3.0 and 4.0V lines on the
graph.  So maybe we'll get 100mA?  Maybe enough?

My multimeter was telling me the GPS consumes 40-60ma while on but I think this
is an average value.  Depending on what the GPS was trying to do, it just
needed more current than the transistor was willing to allow, thus the GPS
ground (MOSFET drain) voltage would rise.  This created both UART errors and
reduced overall voltage to the GPS unit which would sometimes still sort of
work and other times go into a reset loop.

One solution would be to go with a "high side" with an additional P-MOSFET on
top to make it happen.  This eliminates the separate ground issue and provides
a full 5V (battery) gate voltage swing, which will turn the associated P-MOSFET
fully on:

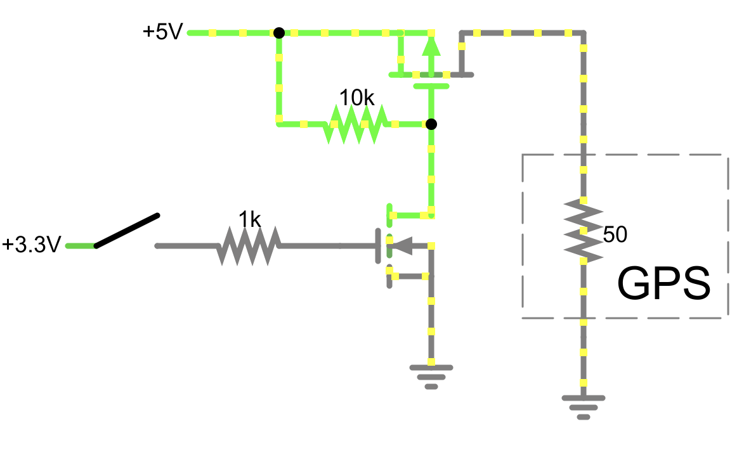
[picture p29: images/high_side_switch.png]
high side switch

[try it out](http://www.falstad.com/circuit/circuitjs.html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)

But in my optimism, I had already ordered PCBs with the lowside wiring so my
secondary solution was to abandon the BS170 and go with a FQP30N06L instead.
This higher-current MOSFET (max 30A!) seems like serious overkill, and it is
but its curves look like this:

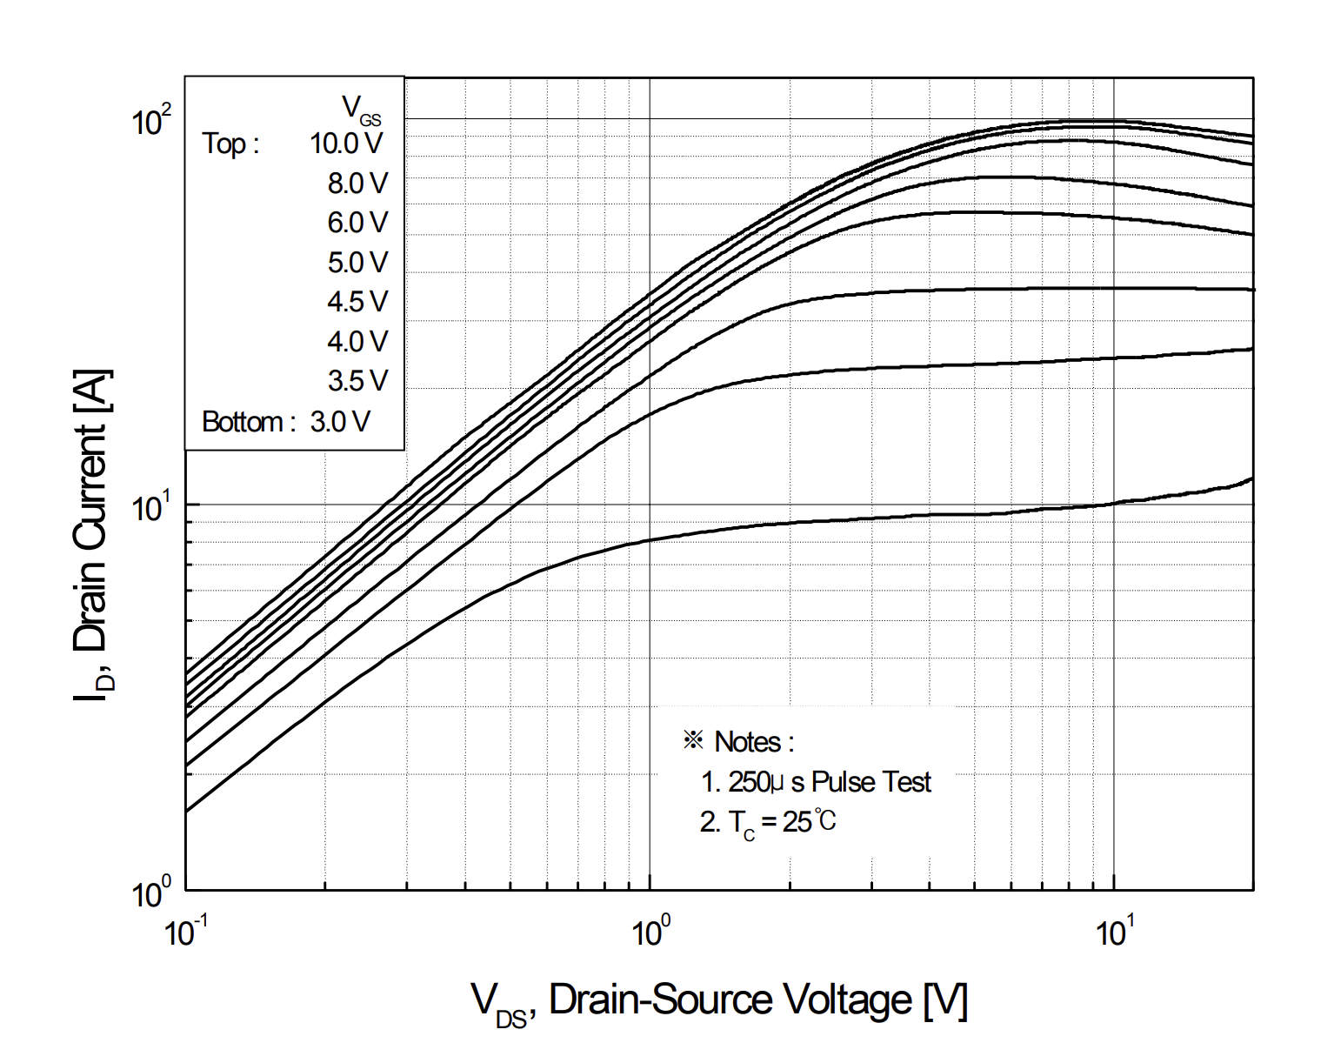
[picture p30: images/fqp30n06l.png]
FQP30N06L Curves


Around 10A of current allowance at 3.3V which is a 100x improvement over the
BS170 and should now be plenty.  And indeed the instabilities have not
returned.

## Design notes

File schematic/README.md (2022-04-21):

Different Hardware Configurations:

   * `arduino_nano_with_cheap_gps`:  The "easy" design which uses a minimum part count
     and is intended to be powered with a USB power adapter.
   * `raw_atmega328p_with_adafruit_gps`: Uses raw Atmega328P and an Adafruit
       GPS unit.  A good match for the 32k oscillator firmware for long battery life.
   * `arduino_pro_mini_with_cheap_gps`: Uses an arduino pro mini with an inexpensive GPS
      unit and MOSFET shutoff.  The pro mini can be hacked with with a 32k oscillator
      (see the main README.md for more info)  

You can mix and match above, for example raw atmega328p + cheap gps, but will need to make
layout corrections (or make a simple adapter board) if you are using the PCB layout.

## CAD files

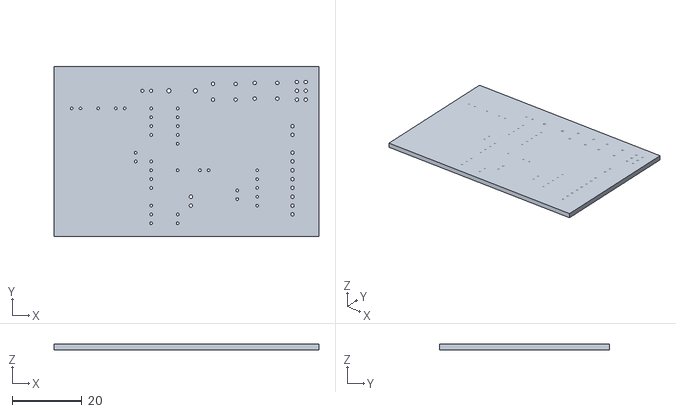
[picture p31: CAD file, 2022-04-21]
case_design/freecad_models/main_pcb.stl
76.2 x 48.9 x 1.60

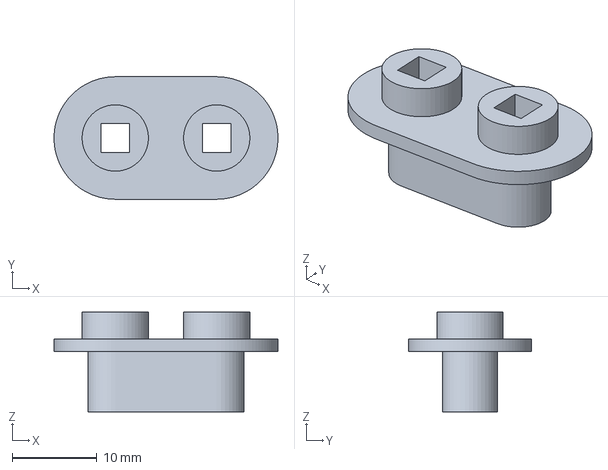
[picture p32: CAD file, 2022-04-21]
case_design/export/button_casing.3mf
26.5 x 14.5 x 11.8 mm

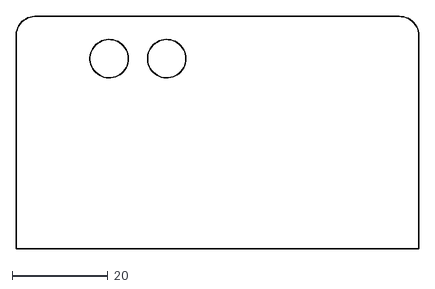
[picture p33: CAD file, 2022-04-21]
case_design/export/top_cover.dxf
84.0 x 48.4

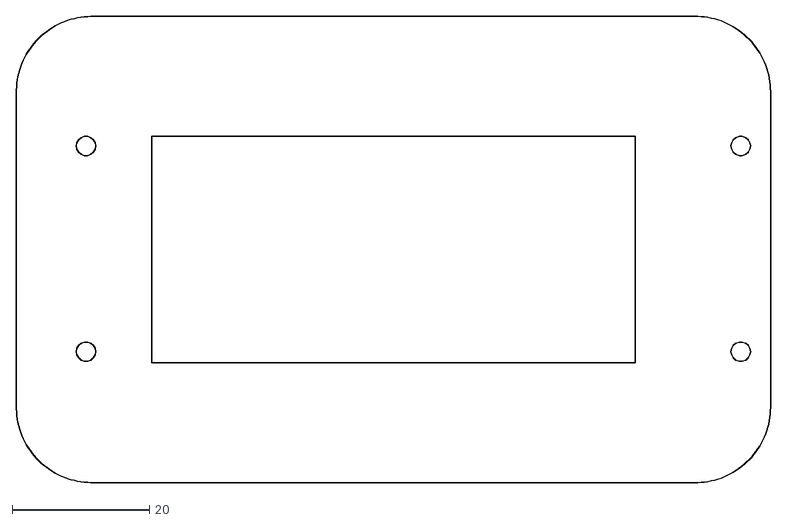
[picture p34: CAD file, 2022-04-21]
case_design/export/face_plate.dxf
110.0 x 68.0

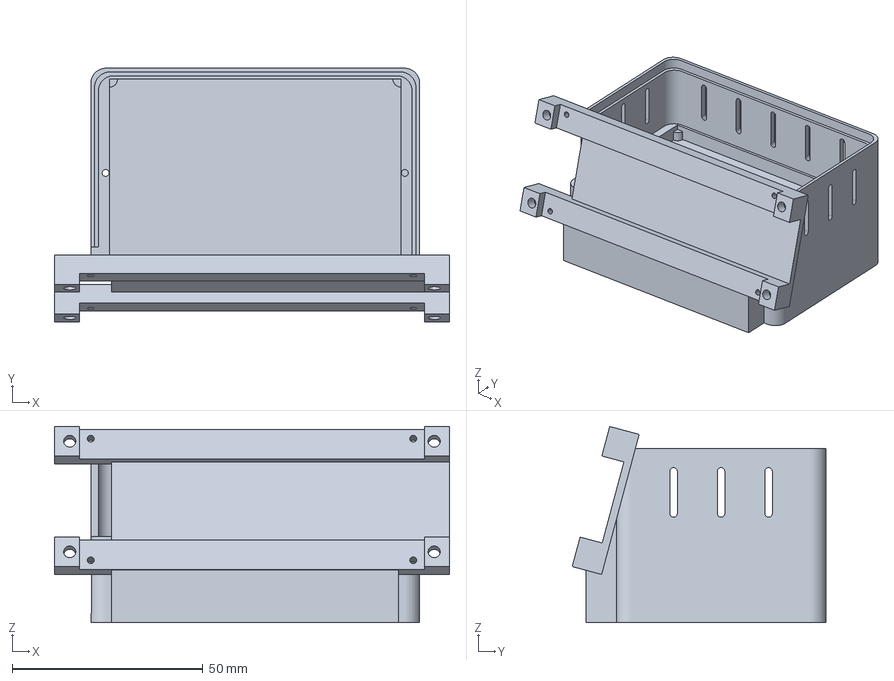
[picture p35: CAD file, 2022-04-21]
case_design/export/epaper_clock_case.3mf
103.5 x 66.5 x 51.4 mm

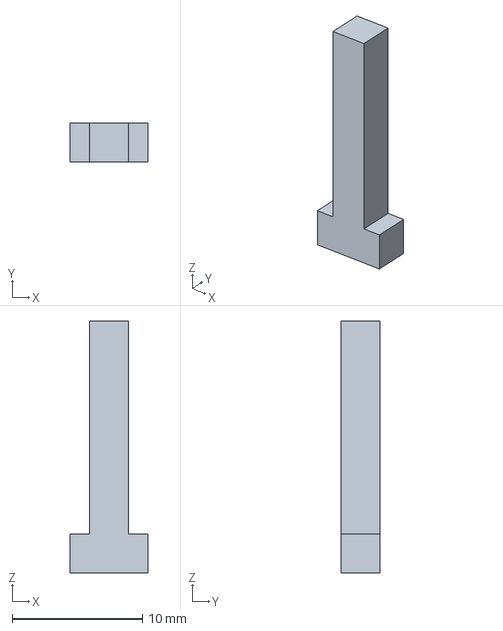
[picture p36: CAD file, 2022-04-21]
case_design/export/button.3mf
6.00 x 3.00 x 19.3 mm

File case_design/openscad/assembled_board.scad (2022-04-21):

use <../lib/mattwach/util.scad>
use <../lib/mattwach/shapes.scad>
include <../lib/mattwach/vitamins/electronics/arduino.scad>
include <../lib/mattwach/vitamins/electronics/capacitor.scad>
include <../lib/mattwach/vitamins/electronics/adafruit_gps.scad>
include <../lib/mattwach/vitamins/electronics/adafruit_ms8607.scad>
include <../lib/NopSCADlib/core.scad>
include <../lib/NopSCADlib/vitamins/axials.scad>
include <../lib/NopSCADlib/vitamins/buttons.scad>
include <../lib/NopSCADlib/vitamins/dip.scad>
include <../lib/NopSCADlib/vitamins/leds.scad>
include <../lib/NopSCADlib/vitamins/pin_headers.scad>

assembled_board_length = 76.2;
assembled_board_width = 48.9;

module assembled_board() {
  board_x_offset = 8.26;
  board_y_offset = 7.63;
  board_thickness = 1.6;
  pin_spacing = 2.54;

  function cx(x) = board_x_offset + x * pin_spacing;
  function cy(y) = board_y_offset + y * pin_spacing;

  module base_pcb() {
    color("#bbb") ty(assembled_board_length) rz(90) ry(180) import("freecad_models/main_pcb.stl");
  }

  module atmega328p_socket() {
    translate([cx(8), cy(14.5), board_thickness]) rz(-90) dil_socket(14, 7.62);
  }

  module atmega328() {
    translate([cx(8), cy(14.5), 4.7]) rz(-90) pdip(28, "ATMega328P", false);
  }

  // This is for height checking the alt circuit design.  It's not intended
  // to represent the V2 board.
  module pro_mini() {
    translate([cx(4), cy(14.5), 12.6]) rz(180) arduino_pro_mini(straight_interface_pins=true);
  }

  module cpu_capacitor() {
     translate([cx(8), cy(17.7), board_thickness]) rz(90) ceramic_capacitor("104");
  }

  module isp_header() {
    translate([cx(-0.5), cy(-1), board_thickness]) pin_header(2p54header, 3, 2);
  }

  module debug_header() {
    translate([cx(12), cy(11.5), board_thickness]) pin_header(2p54header, 2, 1);
  }

  module heartbeat_led() {
    translate([cx(-0.5), cy(16.5), board_thickness]) rz(90) led(LED3mm, "green", 2);
  }

  module led_resistor() {
    translate([cx(-0.5), cy(12.5), board_thickness]) rz(90) ax_res(res1_4, 10000, pitch=8);
  }

  module ms8607_interface() {
    translate([cx(10.5), cy(4), board_thickness]) pin_socket(2p54header, 5, 1);
  }

  module gps_interface() {
    translate([cx(1.5), cy(22), board_thickness]) rz(90) pin_socket(2p54header, 9, 1);
  }

  module epaper_interface() {
    translate([cx(10), cy(0), board_thickness]) jst_xh_header(jst_xh_header, 8);
  }

  module power_connector() {
    translate([cx(4), cy(0), board_thickness]) rz(180) jst_xh_header(jst_xh_header, 2);
  }

  module power_capacitors() {
    module cap() {
      tz(4) ry(90) rx(-90) electrolytic_capacitor(
        diameter=5.2,
        height=11.4,
        pin_spacing=2.54,
        label_text="1u");
    }

    translate([cx(12), cy(5.5), board_thickness]) cap();
    translate([cx(8.5), cy(10.5), board_thickness]) rz(90) cap();
  }

  module buttons() {
    translate([cx(-0.4), cy(7.75), board_thickness]) square_button(button_6mm);
    translate([cx(-0.5), cy(3), board_thickness]) square_button(button_6mm);
  }

  module ms8607() {
    translate([cx(5.5), cy(3), 12.6]) adafruit_ms8607(true);
  }

  module gps() {
    translate([cx(0.7), cy(27), 12.6]) rz(-90) adafruit_gps(true);
  }

  base_pcb();
  atmega328p_socket();
  atmega328();
  *pro_mini();
  cpu_capacitor();
  isp_header();
  debug_header();
  heartbeat_led();
  led_resistor();
  ms8607_interface();
  gps_interface();
  epaper_interface();
  power_connector();
  power_capacitors();
  buttons();
  ms8607();
  gps();
}

/*
$fa=2.0;
$fs=0.5;
assembled_board();
*/

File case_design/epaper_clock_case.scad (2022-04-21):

use <lib/mattwach/util.scad>
use <lib/mattwach/vitamins/bolts.scad>
use <lib/mattwach/shapes.scad>
include <lib/mattwach/vitamins/electronics/aaa_battery_holder_b.scad>
include <lib/mattwach/vitamins/electronics/waveshare_epaper_2.9in.scad>
include <openscad/assembled_board.scad>
include <openscad/buttons.scad>

overlap = 0.01;

epaper_x_offset = 0;
epaper_y_offset = 8;
epaper_z_offset = 16.2;
epaper_display_angle = 75;
face_plate_zoffset = waveshare_epaper_pixel_area_zoffset + 0.3;
pcb_xpadding = 5;
pcb_ypadding = 3;
base_xsize = assembled_board_length + pcb_xpadding * 2;
base_ysize = assembled_board_width + pcb_ypadding * 2;
base_thickness = 18;
top_cover_inset = 1;
top_cover_thickness = 3.175;
top_shell_zsize = 23;
pcb_zpad = 3;
pcb_thickness = 1.6;

button_a_x = 20.5;
button_b_x = 32.5;
button_y = 45;
button_access_hole_diameter = 8;

module base_template(height, inset=0) {
  base_fillet = 4;
  txy(inset, inset) rounded_cube(
      [base_xsize - inset * 2, base_ysize - inset * 2, height], fillet=base_fillet);
}

module epaper_clock_case(add_parts) {
  pcb_bolt_board_offset = 1.1;
  battery_holder_xpad = 9;
  battery_holder_zpad = 0.5;

  module base() {
    aaa_gap_width = aaa_holder_width - 2;
    module aaa_slot() {
      translate([
          -battery_holder_xpad,
          (base_ysize - aaa_holder_width) / 2,
          aaa_holder_height + battery_holder_zpad]) rz(-90) ry(180) aaa_box_opening(gap=0.2);
      translate([
          -overlap,
          (base_ysize - aaa_gap_width) / 2,
          -overlap]) cube([aaa_holder_length - battery_holder_xpad, aaa_gap_width, 10]);
    }

    module pcb_cutout() {
      pcb_cutout_xsize = assembled_board_length + 0.3;
      pcb_cutout_ysize = assembled_board_width + 0.2;
      translate([
          (base_xsize - pcb_cutout_xsize) / 2,
          (base_ysize - pcb_cutout_ysize) / 2,
          base_thickness]) cube([
          pcb_cutout_xsize,
          pcb_cutout_ysize,
          pcb_zpad + pcb_thickness + overlap]);
    }

    module pcb_support_pegs() {
      pcb_support_peg_diameter = 4;
      module support_peg() {
        translate([
            pcb_xpadding,
            (base_ysize - aaa_holder_width) / 2,
            base_thickness - overlap]) cylinder(
              d=pcb_support_peg_diameter, h=pcb_zpad+overlap);
      }

      support_peg();
      tx(assembled_board_length) support_peg();
      txy(assembled_board_length, assembled_board_width) support_peg();
      ty(assembled_board_width) support_peg();
    }

    module pcb_bolt_holes() {
      pcb_bolt_hole_diameter = 1.85;
      pcb_bolt_hole_depth = 8;
      module pcb_bolt_hole() {
        translate([
            pcb_xpadding,
            base_ysize / 2,
            base_thickness + pcb_zpad + pcb_thickness - pcb_bolt_hole_depth + overlap,
        ]) cylinder(d=pcb_bolt_hole_diameter, h=pcb_bolt_hole_depth+overlap);
      }

      tx(-pcb_bolt_board_offset) pcb_bolt_hole();
      tx(assembled_board_length+pcb_bolt_board_offset) pcb_bolt_hole();
    }

    module epaper_interface() {
      module interface_plate() {
        electronics_cutout_width = 22;
        interface_plate_thickness = 5;
        interface_plate_xpad = 7;
        interface_plate_width = waveshare_epaper_length + interface_plate_xpad * 2;
        interface_plate_height = waveshare_epaper_width;

        module main_plate() {
          cube([
            interface_plate_width,
            interface_plate_height,
            interface_plate_thickness]);
        }

        module electronics_cutout() {
          electronics_cutout_height = 3;
          translate([
              -overlap,
              (interface_plate_height - electronics_cutout_width) / 2,
              interface_plate_thickness - electronics_cutout_height
          ]) cube([
            interface_plate_width + overlap * 2,
            electronics_cutout_width,
            electronics_cutout_height + overlap]);
        }

        module connector_cutout() {
          connector_cutout_width = 15;
          translate([
              -overlap,
              (interface_plate_height - electronics_cutout_width) / 2,
              -overlap,
          ]) cube([
            connector_cutout_width + overlap,
            electronics_cutout_width,
            interface_plate_thickness + overlap * 2]);
        }

        module face_plate_holes() {
          face_plate_hole_diameter = 3.2;
          face_plate_hole_offset = 4;
          face_plate_countersink_diameter = 6;
          face_plate_countersink_depth = interface_plate_thickness - 0.5;
          module face_plate_hole() {
            translate([
                0,
                0,
                -overlap]) union() {
                  cylinder(
                    d=face_plate_countersink_diameter,
                    h=face_plate_countersink_depth);
                  tz(face_plate_countersink_depth - overlap) cylinder(
                    d=face_plate_hole_diameter,
                    h=10);
            }
          }

          txy(face_plate_hole_offset, face_plate_hole_offset) face_plate_hole();
          txy(interface_plate_width - face_plate_hole_offset, face_plate_hole_offset) face_plate_hole();
          txy(face_plate_hole_offset, interface_plate_height - face_plate_hole_offset) face_plate_hole();
          txy(interface_plate_width - face_plate_hole_offset, interface_plate_height - face_plate_hole_offset) face_plate_hole();
        }

        module epaper_mount_holes() {
          epaper_mount_hole_diameter = 1.85;
          module hole() {
            translate([
                interface_plate_xpad,
                0,
                -overlap])  cylinder(d=epaper_mount_hole_diameter, h=interface_plate_thickness + overlap * 2);
          }
          txy(waveshare_epaper_bolt_inset, waveshare_epaper_bolt_inset) hole();
          txy(waveshare_epaper_length - waveshare_epaper_bolt_inset, waveshare_epaper_bolt_inset) hole();
          txy(waveshare_epaper_bolt_inset, waveshare_epaper_width - waveshare_epaper_bolt_inset) hole();
          txy(waveshare_epaper_length - waveshare_epaper_bolt_inset,
              waveshare_epaper_width - waveshare_epaper_bolt_inset) hole();
        }

        module face_plate_interface() {
          face_plate_interface_width = 6.5;
          face_plate_interface_height = (interface_plate_height - electronics_cutout_width) / 2;
          module face_plate_interface_tab() {
            tz(interface_plate_thickness - overlap) cube([
                  face_plate_interface_width,
                  face_plate_interface_height,
                  face_plate_zoffset]);
          }
          face_plate_interface_tab();
          tx(interface_plate_width - face_plate_interface_width) face_plate_interface_tab();
          txy(interface_plate_width - face_plate_interface_width,
              interface_plate_height - face_plate_interface_height) face_plate_interface_tab();
          ty(interface_plate_height - face_plate_interface_height) face_plate_interface_tab();
        }

        translate([
            -epaper_x_offset - waveshare_epaper_bolt_inset - interface_plate_xpad,
            -epaper_y_offset,
            epaper_z_offset - waveshare_epaper_bolt_inset
        ]) rx(epaper_display_angle) tz(-4.3) difference() {
          union() {
            main_plate();
            face_plate_interface();
          }
          electronics_cutout();
          connector_cutout();
          face_plate_holes();
          epaper_mount_holes();
        }
      }

      // attached interface plate to main body
      module interface_glue() {
        interface_glue_xsize = base_xsize - 11;
        interface_glue_ysize = epaper_y_offset;
        interface_glue_zsize = epaper_z_offset + 22;
        interface_glue_fillet = 2;
        module block() {
          translate([
              (base_xsize - interface_glue_xsize) / 2,
              -interface_glue_ysize,
              0
          ]) cube([
            interface_glue_xsize,
            interface_glue_ysize + pcb_ypadding,
            interface_glue_zsize]);
        }

        module cutout() {
          translate([
              (base_xsize - interface_glue_xsize) / 2 - overlap,
              -epaper_y_offset + 2.5,
              epaper_z_offset - waveshare_epaper_bolt_inset]) rx(epaper_display_angle) cube([
                interface_glue_xsize + overlap * 2,
                40,
                10]);
        }

        difference() {
          block();
          cutout();
        }
      }

      interface_plate();
      interface_glue();
    }

    module top_shell() {
      top_shell_thickness = 2;
    
      module cutout() {
        cutout_width = 8;
        translate([
            -overlap,
            -overlap,
            0]) cube([
              pcb_xpadding + 2,
              cutout_width + overlap,
              top_shell_zsize + overlap]);
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

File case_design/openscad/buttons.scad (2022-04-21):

use <../lib/mattwach/util.scad>

module buttons(
    hole_diameter,
    hole_thickness,
    hole_span,
    button_size,
    button_depth, // cepth starting at bottom of top plate
    button_protrusion,
    use_hull,
    show_carriage,
    show_button) {

  overlap = 0.01;
  interface_thickness = 1.5;
  button_pad = 0.2;
  base_pad = 6;
  base_diameter = button_size * 2 + 0.5;

  module base() {
    module leg() {
      tz(base_pad) cylinder(
          d=base_diameter,
          h=button_depth - base_pad - interface_thickness);
    }
    hull() {
      leg();
      ty(hole_span) leg();
    }
  }

  module interface() {
    interface_pad = 4;
    module interface_leg() {
      tz(button_depth - interface_thickness - overlap) cylinder(
          d=base_diameter + interface_pad * 2, h=interface_thickness + overlap);
    }
    hull() {
      interface_leg();
      ty(hole_span) interface_leg();
    }
  }

  module hole_plugs() {
    module hole_plug() {
      tz(button_depth - overlap) cylinder(
          d=hole_diameter,
          h=hole_thickness + overlap);
    }

    if (use_hull) {
      hull() {
        hole_plug();
        ty(hole_span) hole_plug();
      }
    } else {
      hole_plug();
      ty(hole_span) hole_plug();
    }
  }

  module button_slots() {
    slot_width = button_size + button_pad * 2;
    module button_slot() {
      translate([
          -slot_width / 2,
          -slot_width / 2,
          base_pad - overlap]) cube([
            slot_width,
            slot_width,
            button_depth - base_pad + hole_thickness + overlap * 2]);
    }

    button_slot();
    ty(hole_span) button_slot();
  }

  module carriage() {
    difference() {
      union() {
        base();
        interface();
        hole_plugs();
      }
      button_slots();
    }
  }

  module button() {
    button_base_height = 3;
    module button_base() {
      button_base_width = 6;
      translate([
          -button_size / 2,
          -button_base_width / 2,
          0]) cube([
            button_size,
            button_base_width,
            button_base_height]);
    }

    module button_rod() {
      translate([
          -button_size / 2,
          -button_size / 2,
          button_base_height - overlap]) cube([
            button_size,
            button_size,
            button_depth - button_base_height + hole_thickness + button_protrusion + overlap]);
    }


    color("red") union() {
      button_base();
      button_rod();
    }
  }

  if (show_carriage) {
    carriage();
  }

  if (show_button) {
    button();
  }
}

/*
$fa=2.0;
$fs=0.5;
buttons(
    hole_diameter=7,
    hole_thickness=3.175,
    hole_span=10,
    button_size=3,
    button_depth=20,
    button_protrusion=1.5,
    show_carriage=true,
    show_button=true);
*/

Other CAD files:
case_design/export/prusa_slicer_pla.3mf

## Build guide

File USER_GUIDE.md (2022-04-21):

# User's Guide

When you power on the unit.  It will use GPS to determine the current time
and position (needed for sunrise/sunset calculations).  While this is happening,
the time may not be correct and the unit will show GPS information that will
dissapear after there is a lock.  It can help to have the clock near a window
at this time.

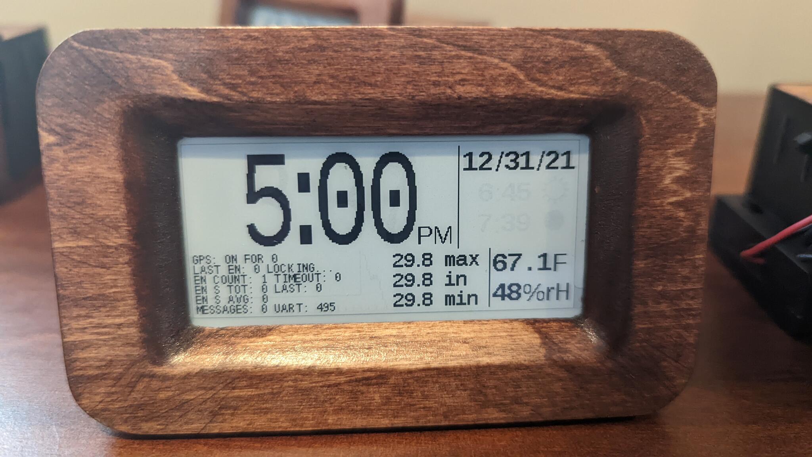
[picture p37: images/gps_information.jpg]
GPS information


After there is a lock, the GPS will turn off for 24 hours.  At this time the clock
will look something like this:

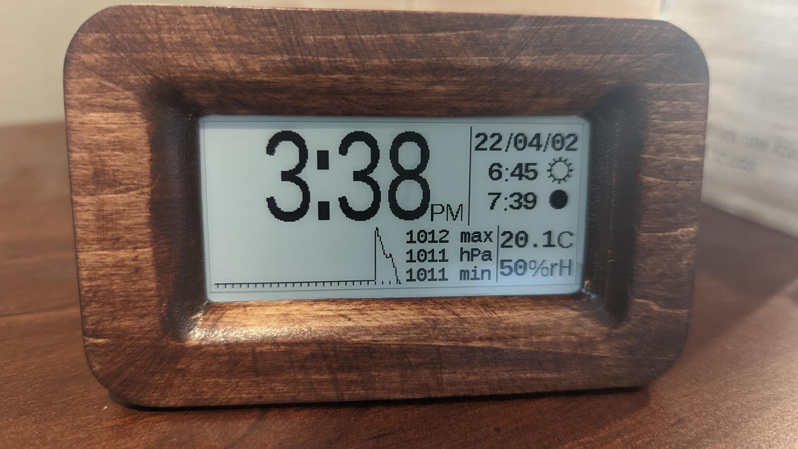
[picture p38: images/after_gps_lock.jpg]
After GPS lock


Time timezone (hour) is likely to be incorrect.  You can fix it in the options menu.
Press the options button (one of the two) and you will see this:

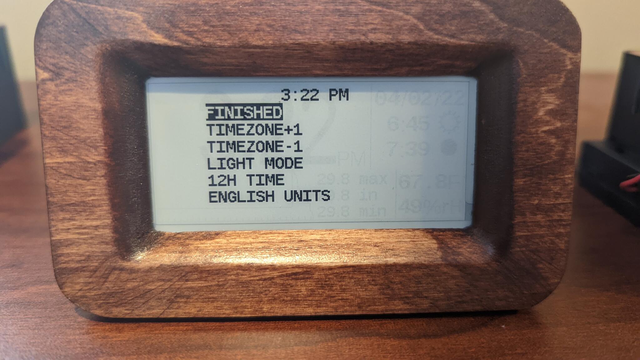
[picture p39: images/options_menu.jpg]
Options Menu


The `TIMEZONE+1` and `TIMEZONE-1` options can correct the hour.  Press the options
button to select your option and the select button to change the option.

Other options include:

   * `FINISHED`: Go back to the clock screen
   * `LIGHT MODE`: Change between "black text on a white background" and
     "white text on a black background"
   * `12H TIME`: Change between 12 and 24 hour time format
   * `ENGLISH UNITS`: Change between English and metric units

## GPS activity

If the GPS locks quickly, it will activate once per day to correct time skew.
For every minute the GPS takes to lock, it will wait an additional day to try
again.  For example, if the GPS takes 3 minutes to lock, it will wait three
days before trying again.  After 10 minutes, GPS will give up trying to lock
and try again 10 days later (assuming you don't turn the clock off and back
on).  This is done to preserve battery life on clocks with bad GPS signals
since correcting time skew is often something that can wait a few days.

## GPS Status Screen

Press the select button to toggle this on and off.  You don't need to
know what the fields mean but if you are curious, here you go:

   * `GPS: ON FOR ...`: How long the GPS has been on for (when it is on)
   * `GPS: NEXT ...`: How many seconds until GPS is turned on again
   * `LAST_EN`: How many seconds ago the GPS was enabled
   * `LAST_LOCK`: How many seconds ago the GPS locked successfully
   * `EN COUNT`: How many times the GPS was turned on
   * `TIMEOUT`: How many times the GPS took 10 minutes and still no lock
   * `EN S TOT`: The total number of seconds the GPS has been on
   * `EN S LAST`: The number of seconds the GPS was on the last time it was enabled.
   * `EN S AVG`: `EN_S_TOT` / `EN_COUNT`
   * `MESSAGES`: How many messages the GPS has sent to the clock
   * `UART`: How many bytes the GPS has sent to the clock

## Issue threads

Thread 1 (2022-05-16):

Replace GPS module with radio-controlled clock module

linuxzilla, 2022-05-16:
# First of all, this project is amazing!

Could you make a solution to replace the gps module with a inexpensive dcf77 (it specific to my region), or with any other radio clock module?

[Link to a cheap DCF77 module on eBay](https://www.ebay.com/itm/181815504817)

mattwach, 2022-05-16:
GPS location is used to calculate sunrise/sunset times.  If switching to a dcf77, the sunrise/sunset feature would need to be dropped from the display.

For many people, this tradeoff would be acceptable and could implemented via compiler flags, but it's not something i would probably get to anytime soon.

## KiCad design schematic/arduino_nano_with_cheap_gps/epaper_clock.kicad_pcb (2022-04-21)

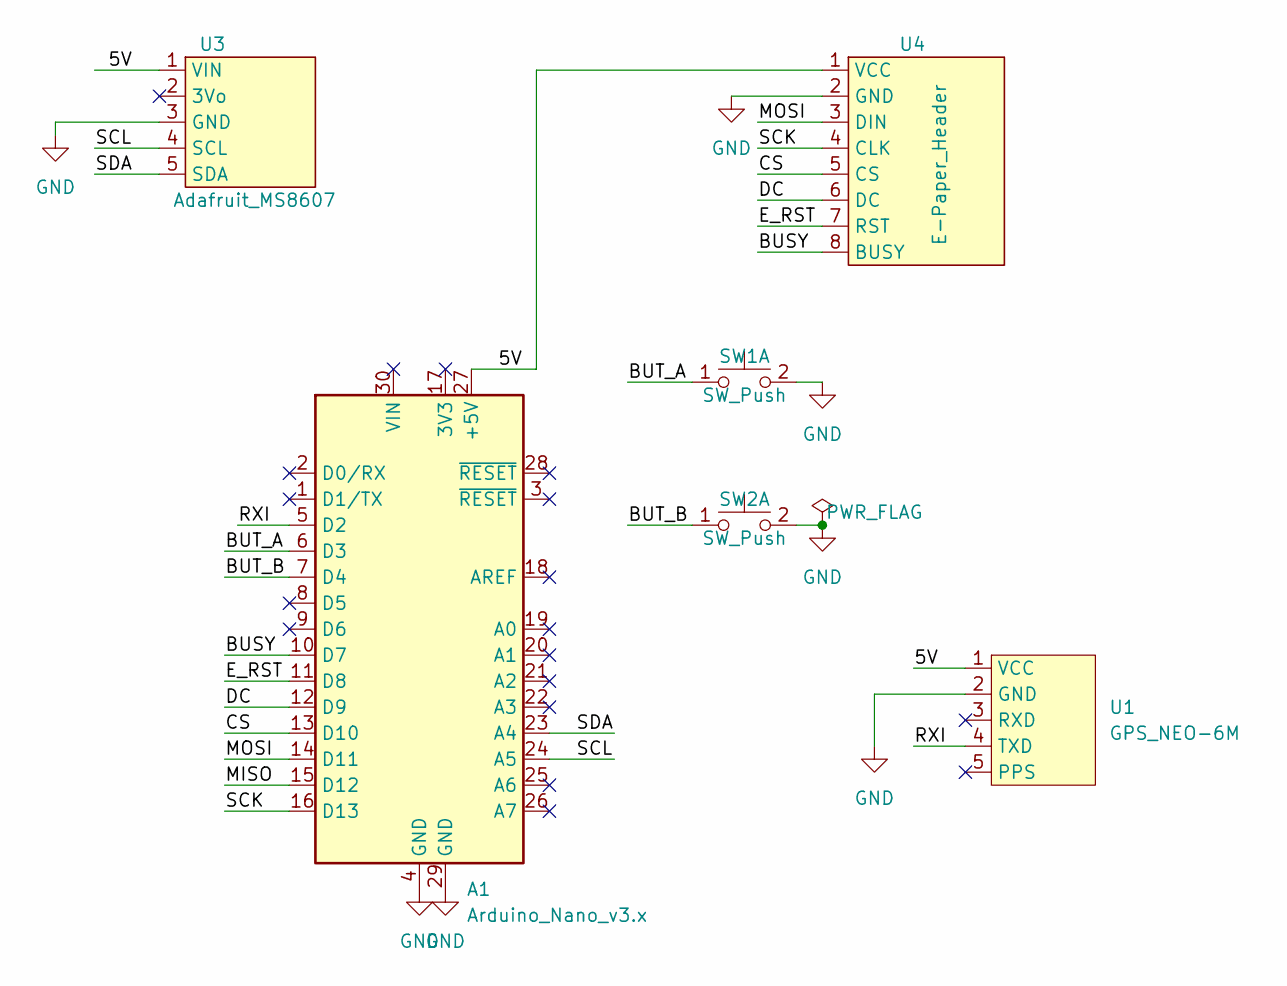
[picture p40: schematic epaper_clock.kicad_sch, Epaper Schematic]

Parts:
A1: Arduino_Nano_v3.x; Arduino_Nano
SW1, SW2: SW_Push; SW_TH_Tactile_Omron_B3F-10xx
U1: GPS_NEO-6M
U3: Adafruit_MS8607
U4: E-Paper_Header; PinHeader_1x08_P2.54mm_Vertical

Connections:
/5V: A1.27 (+5V), U1.1 (VCC), U3.1 (VIN), U4.1 (VCC)
/BUSY: A1.10 (D7), U4.8 (BUSY)
/BUT_A: A1.6 (D3), SW1.1 (C)
/BUT_B: A1.7 (D4), SW2.1 (C)
/CS: A1.13 (D10), U4.5 (CS)
/DC: A1.12 (D9), U4.6 (DC)
/E_RST: A1.11 (D8), U4.7 (RST)
/MISO: A1.15 (D12)
/MOSI: A1.14 (D11), U4.3 (DIN)
/RXI: A1.5 (D2), U1.4 (TXD)
/SCK: A1.16 (D13), U4.4 (CLK)
/SCL: A1.24 (A5), U3.4 (SCL)
/SDA: A1.23 (A4), U3.5 (SDA)
GND: A1.4 (GND), A1.29 (GND), SW1.2 (D), SW2.2 (D), U1.2 (GND), U3.3 (GND), U4.2 (GND)

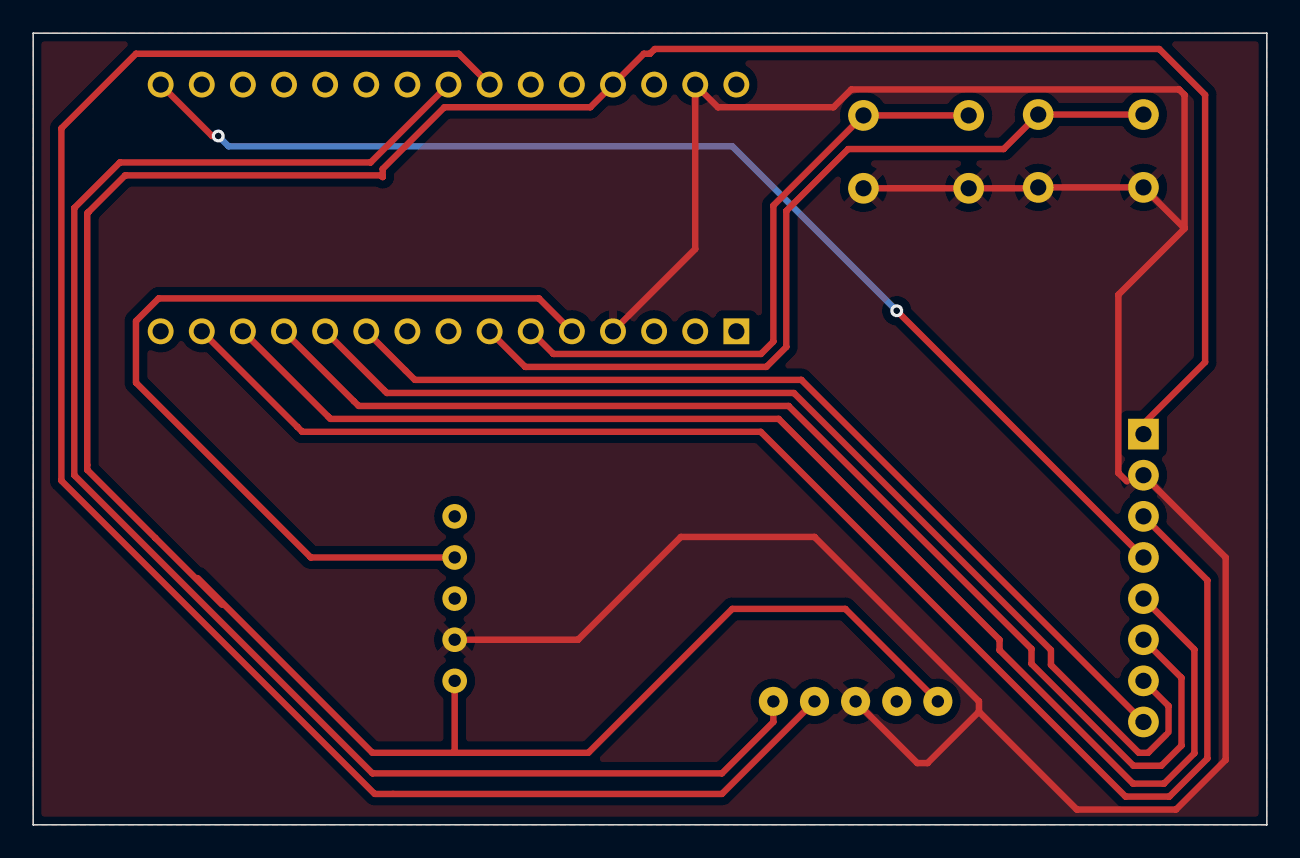
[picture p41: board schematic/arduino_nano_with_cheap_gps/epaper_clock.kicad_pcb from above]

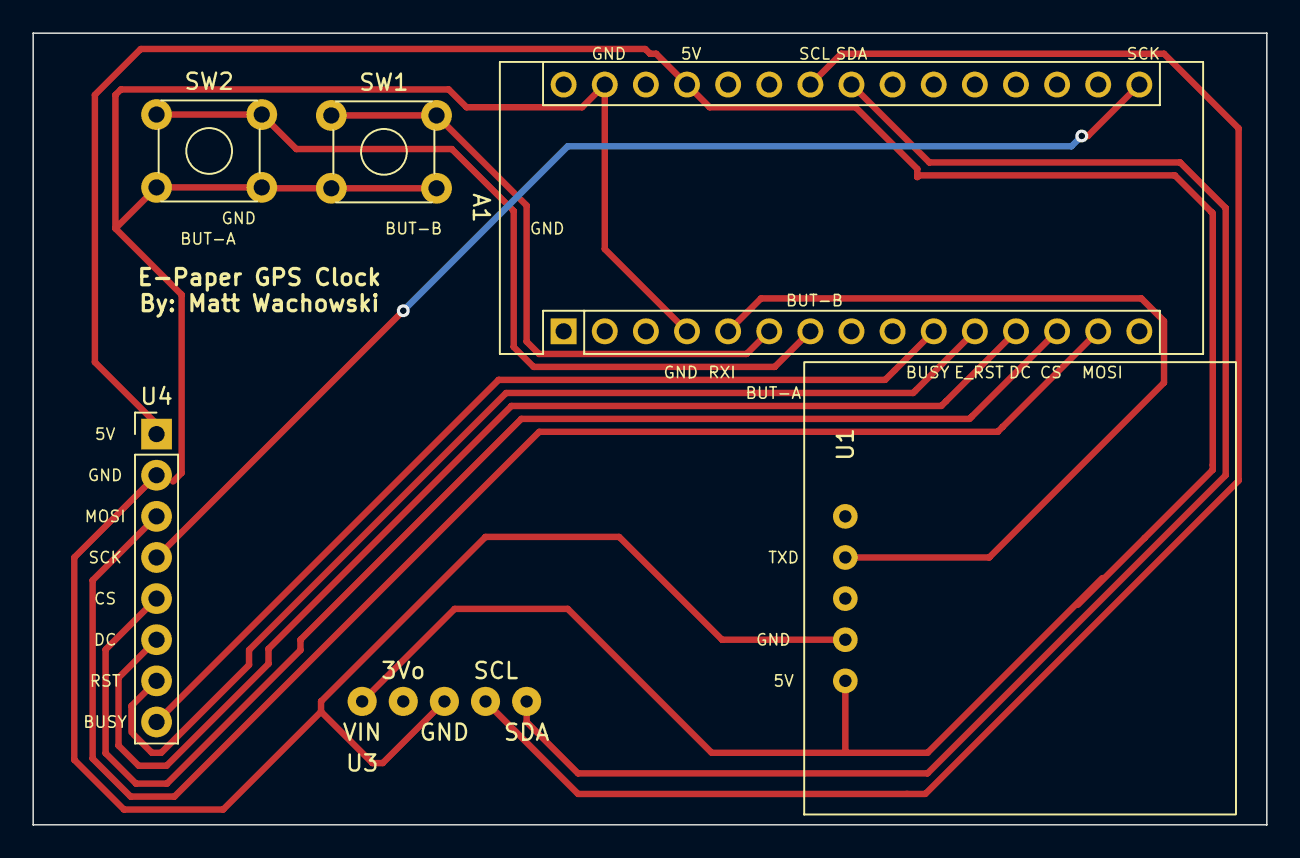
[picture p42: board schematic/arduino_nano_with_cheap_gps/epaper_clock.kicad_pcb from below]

Board: 2 copper layers, 76.2 x 48.9 mm, 6 parts (6 on the bottom side), 13 nets.

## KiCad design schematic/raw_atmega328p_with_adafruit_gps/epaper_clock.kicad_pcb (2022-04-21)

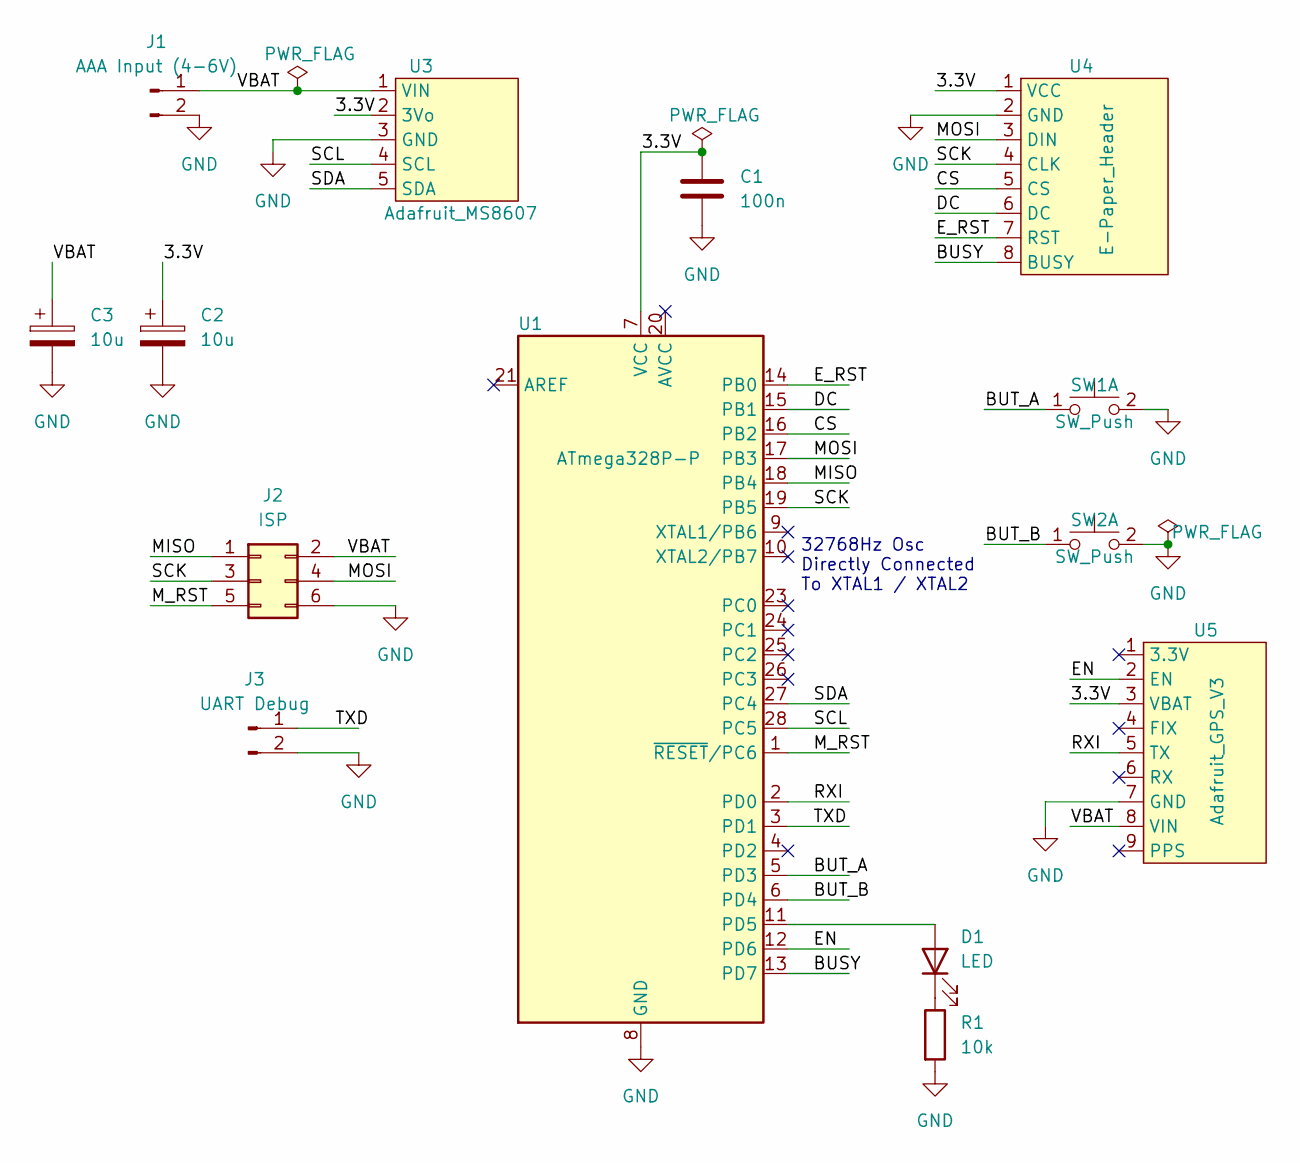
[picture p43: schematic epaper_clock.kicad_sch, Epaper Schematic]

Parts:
C1: 100n; C_Disc_D5.0mm_W2.5mm_P2.50mm
C2, C3: 10u; CP_Radial_D6.3mm_P2.50mm
D1: LED; LED_D3.0mm
J1: AAA Input (4-6V); PinHeader_1x02_P2.54mm_Vertical
J2: ISP; PinHeader_2x03_P2.54mm_Vertical
J3: UART Debug; PinHeader_1x02_P2.54mm_Vertical
R1: 10k; R_Axial_DIN0411_L9.9mm_D3.6mm_P7.62mm_Vertical
SW1, SW2: SW_Push; SW_TH_Tactile_Omron_B3F-10xx
U1: ATmega328P-P; DIP-28_W7.62mm
U3: Adafruit_MS8607
U4: E-Paper_Header; PinHeader_1x08_P2.54mm_Vertical
U5: Adafruit_GPS_V3

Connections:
/3.3V: C1.1, C2.1, U1.7 (VCC), U3.2 (3Vo), U4.1 (VCC), U5.3 (VBAT)
/BUSY: U1.13 (PD7), U4.8 (BUSY)
/BUT_A: SW1.1 (C), U1.5 (PD3)
/BUT_B: SW2.1 (C), U1.6 (PD4)
/CS: U1.16 (PB2), U4.5 (CS)
/DC: U1.15 (PB1), U4.6 (DC)
/EN: U1.12 (PD6), U5.2 (EN)
/E_RST: U1.14 (PB0), U4.7 (RST)
/MISO: J2.1, U1.18 (PB4)
/MOSI: J2.4, U1.17 (PB3), U4.3 (DIN)
/M_RST: J2.5, U1.1 (~RESET/PC6)
/RXI: U1.2 (PD0), U5.5 (TX)
/SCK: J2.3, U1.19 (PB5), U4.4 (CLK)
/SCL: U1.28 (PC5), U3.4 (SCL)
/SDA: U1.27 (PC4), U3.5 (SDA)
/TXD: J3.1, U1.3 (PD1)
/VBAT: C3.1, J1.1, J2.2, U3.1 (VIN), U5.8 (VIN)
GND: C1.2, C2.2, C3.2, J1.2, J2.6, J3.2, R1.2, SW1.2 (D), SW2.2 (D), U1.8 (GND), U1.22 (GND), U3.3 (GND), U4.2 (GND), U5.7 (GND)
unnamed: D1.1 (K), R1.1
unnamed: D1.2 (A), U1.11 (PD5)

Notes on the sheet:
32768Hz Osc Directly Connected To XTAL1 / XTAL2

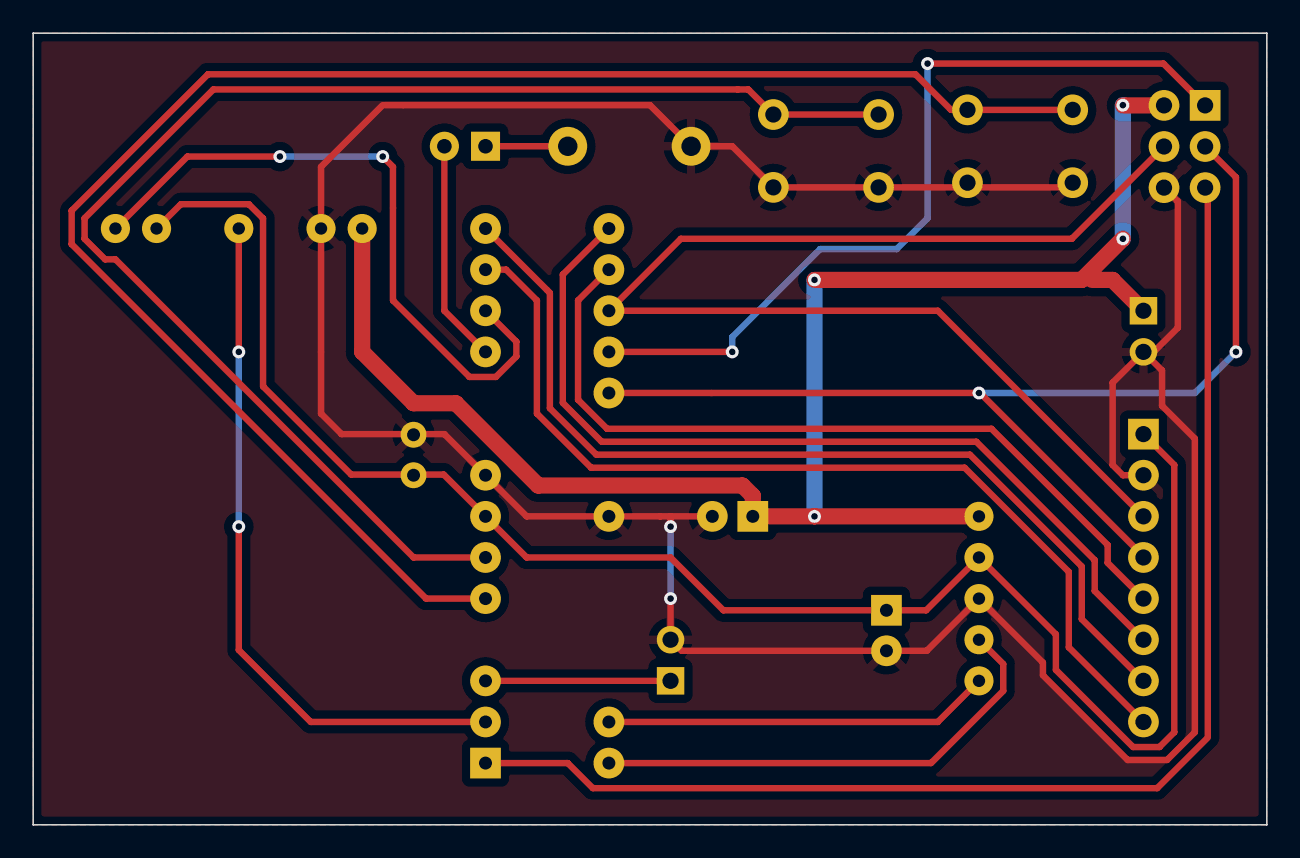
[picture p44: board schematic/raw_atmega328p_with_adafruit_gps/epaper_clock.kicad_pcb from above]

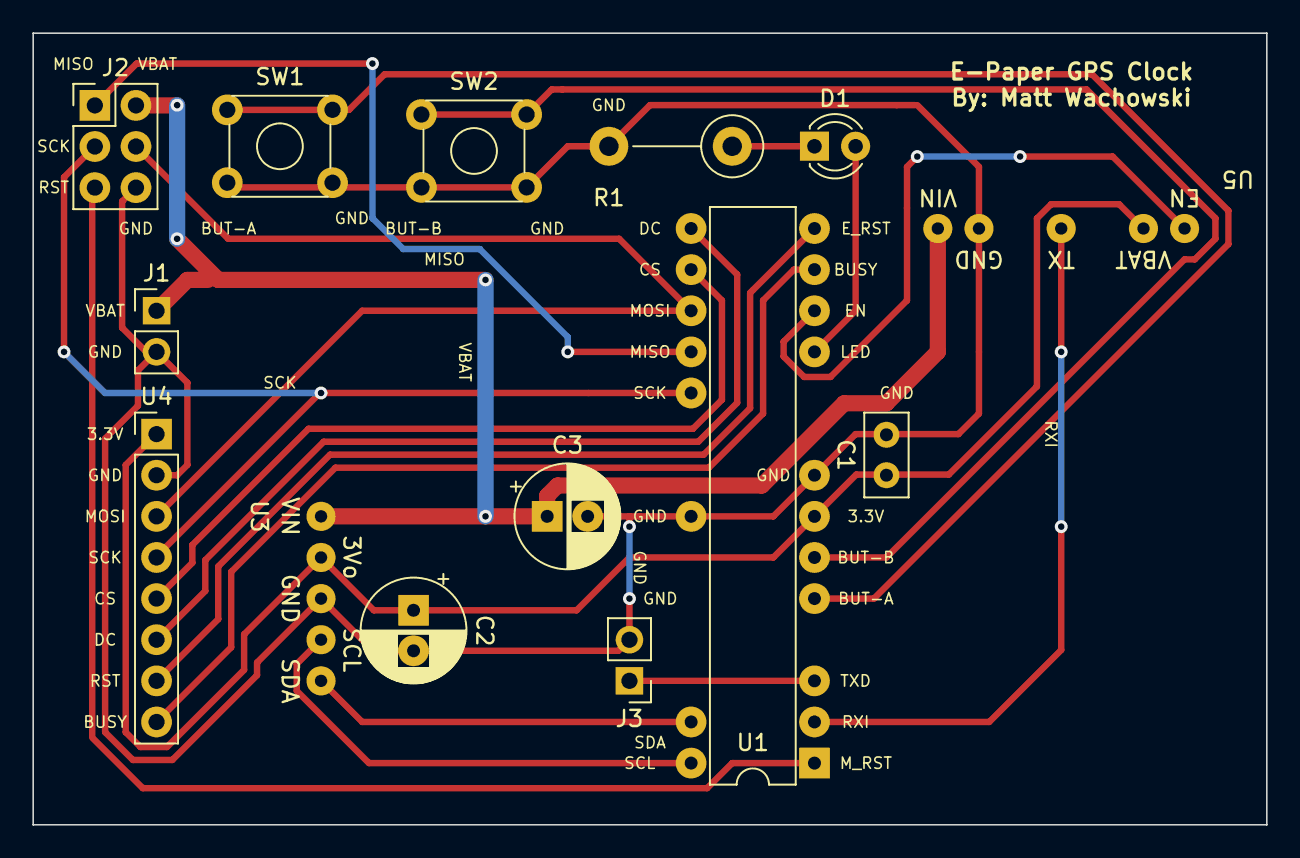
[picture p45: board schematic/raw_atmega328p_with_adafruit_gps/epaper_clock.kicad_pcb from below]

Board: 2 copper layers, 76.2 x 48.9 mm, 14 parts (14 on the bottom side), 20 nets.

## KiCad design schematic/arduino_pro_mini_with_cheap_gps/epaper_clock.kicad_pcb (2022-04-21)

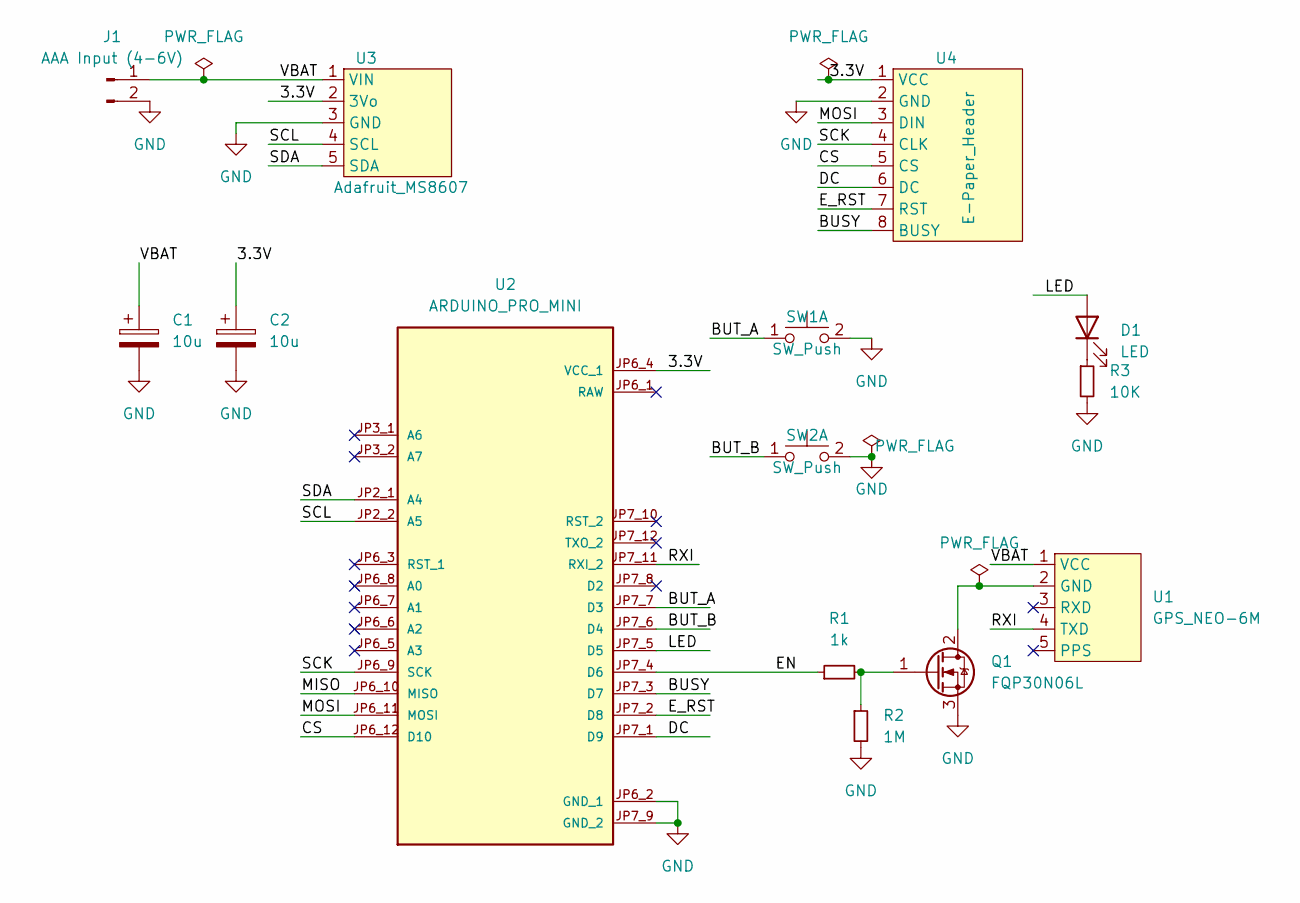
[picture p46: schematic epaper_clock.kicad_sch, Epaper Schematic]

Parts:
C1, C2: 10u; CP_Radial_D6.3mm_P2.50mm
D1: LED; LED_D3.0mm
J1: AAA Input (4-6V); PinHeader_1x02_P2.54mm_Vertical
Q1: FQP30N06L; TO-220-3_Vertical
R1: 1k; R_Axial_DIN0204_L3.6mm_D1.6mm_P5.08mm_Horizontal
R2: 1M; R_Axial_DIN0204_L3.6mm_D1.6mm_P5.08mm_Horizontal
R3: 10K; R_Axial_DIN0204_L3.6mm_D1.6mm_P5.08mm_Horizontal
SW1, SW2: SW_Push; SW_TH_Tactile_Omron_B3F-10xx
U1: GPS_NEO-6M
U2: ARDUINO_PRO_MINI; MODULE_ARDUINO_PRO_MINI; PARTREV N/A
U3: Adafruit_MS8607
U4: E-Paper_Header; PinHeader_1x08_P2.54mm_Vertical

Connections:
/3.3V: C2.1, U2.JP6_4 (VCC_1), U3.2 (3Vo), U4.1 (VCC)
/BUSY: U2.JP7_3 (D7), U4.8 (BUSY)
/BUT_A: SW1.1 (C), U2.JP7_7 (D3)
/BUT_B: SW2.1 (C), U2.JP7_6 (D4)
/CS: U2.JP6_12 (D10), U4.5 (CS)
/DC: U2.JP7_1 (D9), U4.6 (DC)
/EN: R1.1, U2.JP7_4 (D6)
/E_RST: U2.JP7_2 (D8), U4.7 (RST)
/LED: D1.2 (A), U2.JP7_5 (D5)
/MISO: U2.JP6_10 (MISO)
/MOSI: U2.JP6_11 (MOSI), U4.3 (DIN)
/RXI: U1.4 (TXD), U2.JP7_11 (RXI_2)
/SCK: U2.JP6_9 (SCK), U4.4 (CLK)
/SCL: U2.JP2_2 (A5), U3.4 (SCL)
/SDA: U2.JP2_1 (A4), U3.5 (SDA)
/VBAT: C1.1, J1.1, U1.1 (VCC), U3.1 (VIN)
GND: C1.2, C2.2, J1.2, Q1.3 (S), R2.2, R3.2, SW1.2 (D), SW2.2 (D), U2.JP6_2 (GND_1), U2.JP7_9 (GND_2), U3.3 (GND), U4.2 (GND)
unnamed: D1.1 (K), R3.1
unnamed: Q1.1 (G), R1.2, R2.1
unnamed: Q1.2 (D), U1.2 (GND)

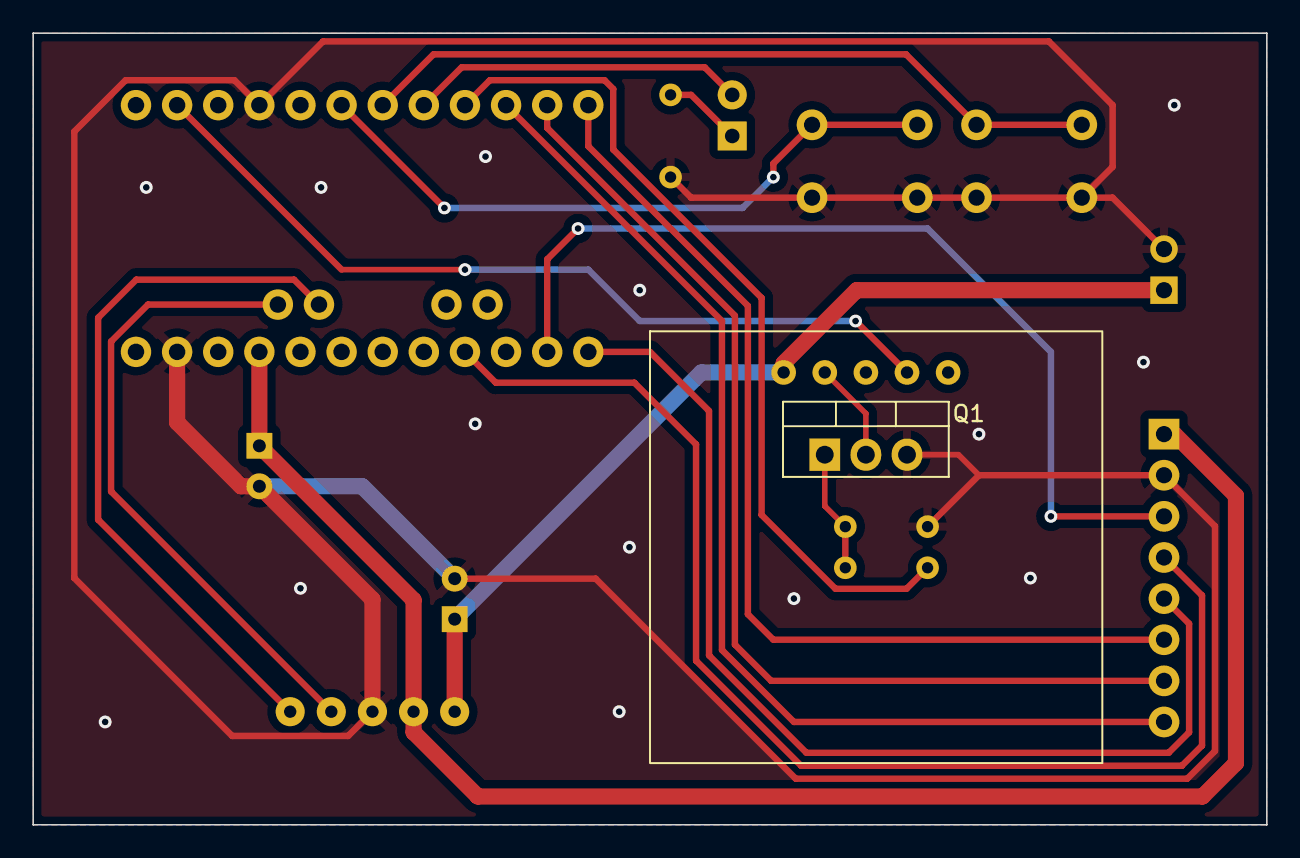
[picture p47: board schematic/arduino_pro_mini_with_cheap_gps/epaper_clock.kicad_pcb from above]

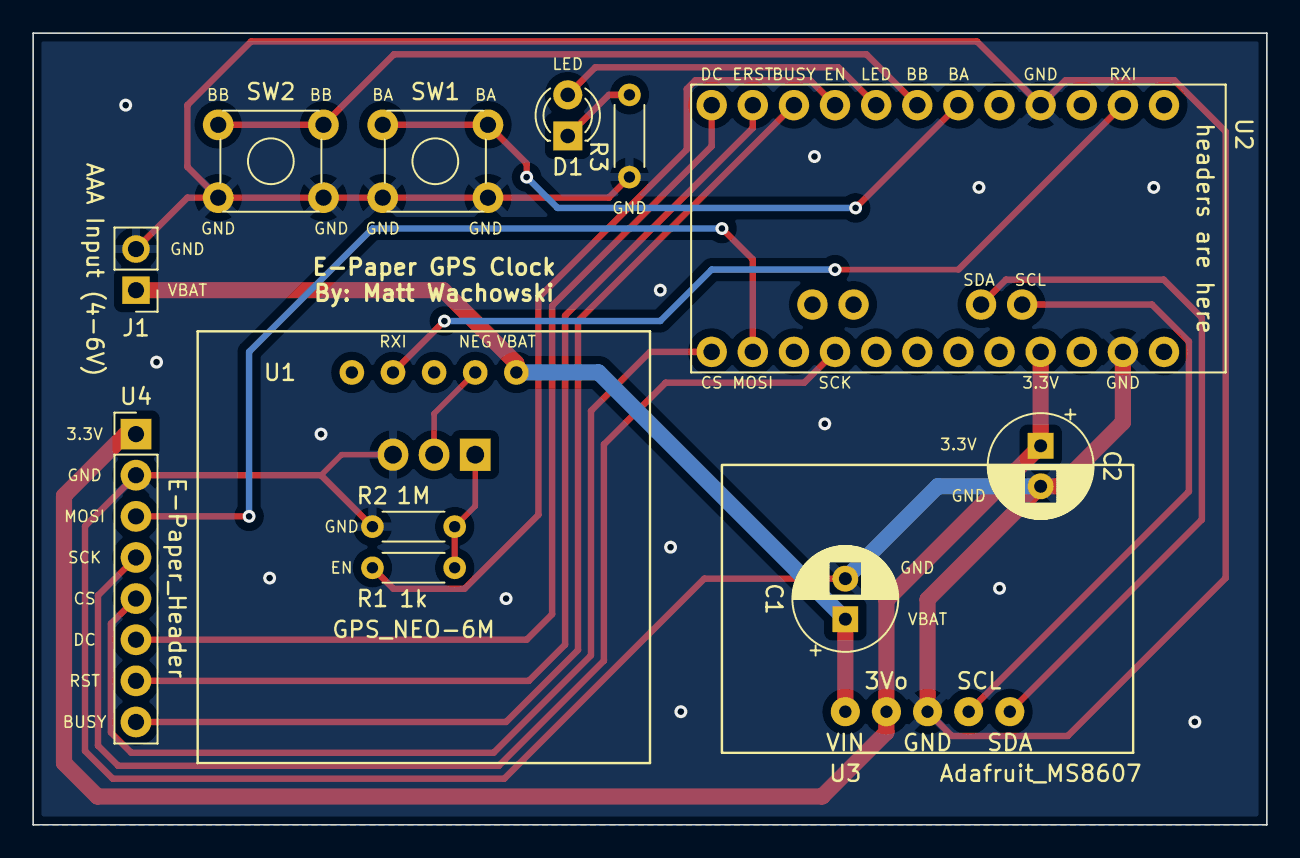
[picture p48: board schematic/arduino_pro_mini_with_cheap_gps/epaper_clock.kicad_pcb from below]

Board: 2 copper layers, 76.2 x 48.9 mm, 14 parts (12 on the bottom side), 19 nets.

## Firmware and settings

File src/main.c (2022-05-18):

// Epaper Clock with Temperature / Humidity and Pressure
//
// Offers different setups:
//
// USE_CPU_CRYSTAL + SOFTWARE_UART:
//  Easier build with a nano.  Intended for use with wall power.
//  A good choice when prototyping and experimenting.
//
// USE_32K_CRYSTAL + HARDWARE_UART:
//  Uses 32k crystal with Atmega328p "standalone" (although a
//  properly stripped pro mini could work).  Should run about a
//  year on AAA batteries.
//
// See schematic/ directory for hardware details (free kicad software
// is needed to view the files).

#include <lowpower/lowpower.h>
#include <port/port.h>
#include <twi/twi.h>
#include <uart/uart.h>
#include <weather/ms8607.h>

#include <avr/interrupt.h>
#include <util/delay.h>
#include <time.h>

#include "buttons.h"
#include "display.h"
#include "eeprom_vars.h"
#include "gps.h"
#include "menu.h"

// Clock drift correction
// If your clock runs too fast or too slow, then you can enable these
//#define CORRECT_CLOCK_DRIFT
// number of seconds that a second should be added or removed
//#define CLOCK_DRIFT_SECONDS_PER_CORRECT 1800
// define this if thwe clock is too slow, otherwise leave it commented out
//#define CLOCK_DRIFT_TOO_SLOW

// When using 32k crystal + hardware UART, the HEARTBEAT flashes for 1ms every
// second and tells us that the clock is working and the code is not hung up.
//
// CPU crystal + software uart flashes the LED in the main loop instead of the
// interrupt so that timing-critical software uart interrupts are not delayed (even
// 1ms of delay is a problem).  This means a more erratic update but it does
// settle down to abuot 1 update per second after the GPS locks.
#define HEARTBEAT_LED_DDR DDRD
#define HEARTBEAT_LED_PORT PORTD
#define HEARTBEAT_LED_PIN 5

#if defined(USE_32K_CRYSTAL) && defined(USE_CPU_CRYSTAL)
  #error Define USE_32K_CRYSTAL or USE_CPU_CRYSTAL, not both.
#endif

#if defined(HARDWARE_UART) && defined(SOFTWARE_UART)
  #error Define HARDWARE_UART or SOFTWARE_UART, not both.
#endif

#if defined(USE_32K_CRYSTAL) && defined(SOFTWARE_UART)
  #error SORTWARE_UART and USE_32K_CRYSTAL are not tested to work together.  Remove this error from main.c at your own risk.
#endif

// Pressure/Humidity/Temperature (PHT) sensor calibration data
struct MS8607 ms8607;
// Seconds since Jan 1, 2000.  avr time.h functions use this format.
// Don't access this value directly because the interrupt handler increments it.
// Instead use snapshot_time_y2k which will disable interrupts and grab a snapshot of
// the value.
volatile time_t current_time_y2k;

// Stores non-volatile settings, like UTC time offset and 12/24h preference.
struct EEPromVars eeprom;

// This is needed to allow the LCD to come up after a low power state (which
// turns off SPI and leaves things in a bit of a mess).
void oledm_ifaceInit(void);

// A simple boolean that is set after the GPS has locks a position, it will stay
// true even if the GPS loses it's lock (in which case we assume the location
// can not changed).
uint8_t position_set_trigger;

// A flag that says if we are in the setting menu or not
uint8_t menu_mode;

#ifdef CORRECT_CLOCK_DRIFT
time_t next_clock_drift_correction;
#endif

// Call this to get the current time.  Avoid accessing current_time_y2k
// directly becuase there is a risk of the interrupt handler updating
// the time while in the middle of reading it.
static inline time_t snapshot_time_y2k(void) {
  cli();
  const time_t snapshot = current_time_y2k;
  sei();
  return snapshot;
}

static inline void heartbeat_on(void) {
  HEARTBEAT_LED_PORT |= (1 << HEARTBEAT_LED_PIN);
}

static inline void heartbeat_off(void) {
  HEARTBEAT_LED_PORT &= ~(1 << HEARTBEAT_LED_PIN);
}

static void heartbeat(void) {
  // Turning on the heartbeat LED for 1ms uses almost no power and due to
  // photoluminescence / persistance of vision, the flash can still be easily
  // detected by the human eye.  Without a "heartbeat" it's really hard to tell
  // if the unit is powered on and working properly.
  heartbeat_on();
  _delay_ms(1);
  heartbeat_off();
}

#if defined(USE_32K_CRYSTAL)
  static void timer_init(void) {
    ASSR = 0x20; // Enable the external 32k oscillator
    TCCR2B = 0x05; // Divide by 128 (for an overflow once per second)
    TIMSK2 = (1 << TOIE2);  // Interrupt on timer 2 overflow
  }
#elif defined(USE_CPU_CRYSTAL)
  static void timer_init(void) {
    OCR1A = (F_CPU >> 8);  // when to fire the interrupt (when using the / 256 prescaler)
    TIMSK1 = 1 << OCIE1A; // Interrupt match on counter 1
    TCCR1B = (1 << WGM12) | 0x04;  // OCR1A is top, / 256 count
  }
#else
  #error Please define either USE_32K_CRYSTAL or USE_CPU_CRYSTAL
#endif


// lowpower idle is a bit complicated due to all of the ifdefs,
// so it's movced to it's own separate function.
inline static void idle(void) {
  lowpower_idle(
      SLEEP_FOREVER,
      ADC_OFF,
#if defined(USE_32K_CRYSTAL)
      TIMER2_ON,
      TIMER1_OFF,
#elif defined(USE_CPU_CRYSTAL)
      TIMER2_OFF,
      TIMER1_ON,
#endif
#if defined(HARDWARE_UART)
      TIMER0_OFF,
#elif defined(SOFTWARE_UART)
      TIMER0_ON,  // Software UART needs timer 0 to function
#endif
      SPI_OFF,
#if defined(HARDWARE_UART) || defined(DEBUG)
      USART0_ON,
#elif defined(SOFTWARE_UART)
      USART0_OFF,
#endif
      TWI_OFF);
} 

static void wait_for_next_second(void) {
#ifdef SOFTWARE_UART
  // We can't blink in the interrupt handler so blink here instead
  heartbeat();
#endif

#if defined(USE_32K_CRYSTAL)
  if (menu_mode || gps_is_enabled()) {
    // GPS is enabled so we need to use the idle form of power save
    // to be able to receive the UART interrupts

    // In menu_mode we choose idle becuase the low-latency screen updates are
    // already using power and it reduces the number of overall system
    // states (e.g. we don't have to separately test menu+idle and
    // menu+powersave).  Also the menu state is expected to be a rare event.
    idle();
  } else {
    // GPS is powered down so we can use the ultra low power 32k oscillator
    // mode.
    lowpower_powerSave(SLEEP_FOREVER, ADC_OFF, BOD_OFF, TIMER2_ON);
  }
#elif defined(USE_CPU_CRYSTAL)
  // Always use idle mode when going with the cpu crystal
  // as power save would just lock things up.
  idle();
#else
  #error Please define either USE_32K_CRYSTAL or USE_CPU_CRYSTAL
#endif

  // check on every wait to provide relief to the GPS receive buffer, which may
  // not be large enough to endure several rounds of information (waiting too long
  // leads to new messages being lost until the buffer is processed)
  check_gps(&current_time_y2k);  // Using current_time_y2k on purpose so it can get updated
}


#if defined(USE_32K_CRYSTAL)
  static uint8_t timer_ticks(void) {
    return TCNT2;
  }
#elif defined(USE_CPU_CRYSTAL)
  static uint8_t timer_ticks(void) {
    // can't read TCNT1H directly because it is only updated when TCNT1L is read
    return (TCNT1 >> 8);
  }
#else
  #error Please define either USE_32K_CRYSTAL or USE_CPU_CRYSTAL
#endif

// one-time initialization function that calls several helpers
static void init(void) {
  // eventually, this will come from GPS
  menu_mode = 0;
  current_time_y2k = 694310400; // should be 1/1/2022
  set_system_time(current_time_y2k);
  position_set_trigger = 0;
  load_eeprom(&eeprom);
  set_zone(((int32_t)eeprom.utc_offset) * ONE_HOUR);
  // Set unused pins as pullups
  // All PB pins are used
  // PC0, PC1, PC2, PC3 are unused
  PORTC |= (1 << 0) | (1 << 1) | (1 << 2) | (1 << 3);
  // PD1, PD2 are unused (PD2 is used by software uart but that will be
  // fixed in gps_init() below).
  PORTD |= (1 << 1) | (1 << 2);
  buttons_init(timer_ticks);
  oledm_ifaceInit();
  display_enable_spi();
  HEARTBEAT_LED_DDR |= (1 << HEARTBEAT_LED_PIN);
  _delay_ms(200);
  // If the UTC button was held on startup, never enable GPS.  This is
  // for power measurement
  gps_init(!select_button_is_pressed(), current_time_y2k);
  ms8607_init(&ms8607);
  timer_init();
  sei();  // enable global interrupts
  display_init();
}

// Sample data from the Pressure/Humidity/Temperature sensor
// and update the epaper display with the latest information.
static void collect_data_and_update_display(uint8_t button_pressed, const time_t current_ytk) {
  if (menu_mode) {
    // menummode uses the higher-power eapaper fast-update
    // thus we do not disable SPI
    menu_mode = update_menu(button_pressed, current_ytk, &eeprom);
    button_pressed = 0;  // Don't carry button_pressed across mode changes
  } else if (button_pressed == OPTION_WAS_PRESSED) {
      menu_mode = 1;
      display_enable_spi();
      menu_init(current_ytk, &eeprom);
  }

  if (!menu_mode) {
    const struct GPSStats* gps_stats = gps_get_stats();
    struct DisplayInfo dinfo;
    dinfo.time_y2k = current_ytk;
    dinfo.position_was_set = gps_position_was_set();

    if (button_pressed == SELECT_WAS_PRESSED) {
      gps_stat_show_policy(
        (gps_stats->show_policy == GPS_STATS_HIDE) ?
          GPS_STATS_SHOW :
          GPS_STATS_HIDE);
    }

    display_enable_spi();
    ms8607_read_values(
        &ms8607, &(dinfo.temp_cc), &(dinfo.pressure_pa), &(dinfo.humidity_cpct));
    update_display(&dinfo, &eeprom, wait_for_next_second);
    display_disable_spi();
  }
}

// called when the chip is awoken from sleep, usually once per second
// but possibly more often, ofr example if a button is pressed or new
// GPS data is received.
static time_t loop(time_t next_update) {
  // Update if GPS says so or enough time has passed to advance to the next
  // minute
  const uint32_t current_ytk = snapshot_time_y2k();
  uint32_t difference = current_ytk > next_update ?
    current_ytk - next_update :
    next_update - current_ytk;
  const uint8_t position_was_set = gps_position_was_set();
  const uint8_t button_pressed = button_was_pressed();

  if ((difference >= 60) ||
      (current_ytk >= next_update) ||
      (position_set_trigger != position_was_set) ||
      button_pressed) {
    clear_button_press_state();
    collect_data_and_update_display(button_pressed, current_ytk);
    next_update = current_ytk + 60;
    const uint8_t r = next_update % 60;
    // accurate within one second as the GPS and 32k clock are not in sync
    if ((r > 0) && (r < 59)) {
      // This can happen when GPS sets the time.  Align the next update
      // with the next minute
      next_update -= r;
    }
    if (position_was_set) {
      // one time trigger when position is made available
#ifdef CORRECT_CLOCK_DRIFT
      if (!position_set_trigger) {
        next_clock_drift_correction = current_ytk + CLOCK_DRIFT_SECONDS_PER_CORRECT;
      } else if (current_ytk >= next_clock_drift_correction) {
        cli();
#ifdef CLOCK_DRIFT_TOO_SLOW
        ++current_time_y2k;
#else
        --current_time_y2k;
#endif
        sei();
        next_clock_drift_correction += CLOCK_DRIFT_SECONDS_PER_CORRECT;
      }
#endif
      position_set_trigger = position_was_set;
    }
  }

  return next_update;
}

// Code starts with this function
int main(void) {
  init();
  time_t next_update = snapshot_time_y2k();

  while (1) {
    wait_for_next_second();
    next_update = loop(next_update);
  }
}

// Called whenever Timer2 overflows from 0xff -> 0x00 which as-configured with
// a 32768Hz crystal, will happen once per second.
#if defined(USE_32K_CRYSTAL)
ISR(TIMER2_OVF_vect)
#elif defined(USE_CPU_CRYSTAL)
ISR(TIMER1_COMPA_vect)
#else
  #error Please define either USE_32K_CRYSTAL or USE_CPU_CRYSTAL
#endif
{
#ifdef HARDWARE_UART
  // The 1ms delay messes up the timing of the software uart
  heartbeat();
#endif
  ++current_time_y2k;
}

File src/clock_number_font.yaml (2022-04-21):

# Use make_var_font.py
output_type: VariableFont

# Every character must have the same height
rows: 10

# The rest is a concatenated set of sections.  If any section
# overlaps a previous section, an error will be raised.
sections:
  - type: ttf
    path: LiberationMono-Regular.ttf
    font_size: 104
    col_width: 56
    x_scale: 0.71429
    x_offset: -4
    y_offset: -13
    chars: " 0123456789"
  - type: ttf
    path: LiberationMono-Regular.ttf
    font_size: 104
    col_width: 23
    x_scale: 0.71429
    x_offset: -21
    y_offset: -13
    chars: ":"

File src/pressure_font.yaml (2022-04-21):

# Use make_var_font.py
output_type: VariableFont

# Every character must have the same height
rows: 2

# The rest is a concatenated set of sections.  If any section
# overlaps a previous section, an error will be raised.
sections:
  - type: ttf
    path: LiberationMono-Bold.ttf
    font_size: 16
    y_offset: 0
    left_trim: 1
    right_trim: 2
    #x_scale: 0.75
    chars: "AM"
  - type: ttf
    path: LiberationMono-Bold.ttf
    font_size: 16
    y_offset: 0
    left_trim: 2
    right_trim: 2
    #x_scale: 0.75
    chars: " :+-0123456789inhCDEFGHIKLNOPRSTUZmx"
  - type: ttf
    path: LiberationMono-Bold.ttf
    font_size: 16
    y_offset: 0
    left_trim: 2
    right_trim: 1
    #x_scale: 0.75
    chars: "a"
  - type: ttf
    path: LiberationMono-Bold.ttf
    font_size: 16
    y_offset: 0
    left_trim: 4
    right_trim: 4
    #x_scale: 0.75
    chars: "."

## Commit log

2022-04-21 Initial snapshot from my private repo.
    [assembled_board.scad, button.3mf, button_casing.3mf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]
2022-05-18 Fixed UTC offset range.
    It was 0 to 23 but should have been -12 to 14.
    [main.c]
2022-05-25 Correct moon phase assignment.
    [display.c]
2022-07-09 Adding a new build for an arduino pro mini 3.3V @ 8mhz.
2022-07-10 Fix arduino pro mini hex file (accidently copied the elf file).
